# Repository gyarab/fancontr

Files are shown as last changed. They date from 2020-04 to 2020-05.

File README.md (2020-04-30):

# Rozcestník

- `dokumentace.pdf` -- Dokumentace v PDF
- `dokumentace/` -- Zdrojové soubory dokumentace
- `hw_foto/` -- Fotodokumentace hardwaru
- `firmware/` -- Zdrojový kód firmwaru
- `kicad_v1/` -- KiCad projekt hardwaru v1
	- `kicad_v1/fancontr.pdf` -- PDF schématu
	- `kicad_v1/bom/ibom.html` -- Interaktivní zobrazení tištěného spoje
- `kicad_v2_wip/` -- KiCad projekt hardwaru v2 (nefinální!)
	- `kicad_v2_wip/fancontr.pdf` -- PDF schématu
	- `kicad_v2_wip/bom/ibom.html` -- Interaktivní zobrazení tištěného spoje

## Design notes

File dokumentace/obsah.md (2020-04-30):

# Hardware

Hardwarová část ročníkové práce má formu zařízení, které je určeno k vložení do
počítače a připojení k jeho zdroji, je možné jej ale používat i mimo počítač s
externím zdrojem.

Návrh obvodu a tištěného spoje byl proveden v svobodném softwaru KiCad a
tištěné spoje vyrobila společnost JiaLiChuang Co., Limited (JLCPCB)[^101].

Jako součást ročníkové práce odevzdávám první verzi hardwaru, v1, která je zde
dále popsána.

Hardware řídí mikrokontrolér STM32F103C8T6[^102] založený na jádře ARM
Cortex-M3.  Přímo na něj je napojeno pět konektorů pro čtyřpinové ventilátory,
které jsou přímo regulovány PWM výstupem mikrokontroléru. Dalších šest
třípinových ventilátorů je regulováno obvodem na bázi spínacího zdroje.

Regulační obvod třípinových ventilátorů

Tento obvod lze rozdělit na část spínací a filtrační. Hlavní komponentou
spínací části je P-kanálový MOSFET, který je aktivován jednoduchou kombinací
N-kanálového MOSFETu a pull-up resistoru. Filtrační část pak sestává z LC
low-pass filtru. Využití high-side přepínání umožňuje připojit
tachometrický signál přímo k mikrokontroléru, jelikož zem ventilátoru je
připojena přímo k celkové zemi zařízení.

Součástí zařízení je i USB konektor, který měl sloužit ke komunikaci s
počítačem. I přes použití referenčního designu od výrobce mikrokontroléru ale
není rozhraní v aktuální verzi USB funkční, je tedy místo něj používán sériový
port s dedikovaným převodníkem.

[^101]: <https://jlcpcb.com/>
[^102]: <https://www.st.com/en/microcontrollers-microprocessors/stm32f103c8.html>

# Software

Firmware je napsán v jazyce C nad operačním systémem ChibiOS. Dokáže bez
připojení k externímu zařízení automaticky regulovat otáčky ventilátorů podle
teplotních dat.

Komunikace pro nastavování teplotně-otáčkových křivek a případné aktualizace
hodnot virtuálních zdrojů teplotních dat je realizována příkazovou řádkou. Tuto
komunikaci lze provádět manuálně s pomocí jakéhokoliv sériového terminálu nebo
automatizovat.

## Přehled příkazů

- `fan_list`  
  Přehled všech portů na ventilátory a rychlosti k nim aktuálně připojených
  ventilátorů.
- `fan_set_tempsrc <fan> <tempsrc>`  
  Nastaví zdroj teplotních dat, který bude řídit rychlost daného ventilátoru.
- `fan_set_gmap <fan> (<temp> <speed>)+`  
  Nastaví křivku závislosti rychlosti ventilátoru na teplotě.
- `fan_get_gmap <fan>`  
  Vypíše křivku závislosti rychlosti ventilátoru na teplotě.
- `tempsrc_list`  
  Přehled všech zdrojů teplotních dat a jejich hodnot.
- `tempsrc_virt_set <tempsrc> <value>`  
  Nastaví hodnotu zdroje teplotních dat.

# Diskuse

## Hardware

Hardwarová část projektu prošla v rámci vývoje několika iteracemi.

Nejproblematičtější částí byl obvod pro ovládání třípinových ventilátorů. Jeho
základní princip je skoro shodný s variabilním zdrojem napětí (buck DC-DC
converter), jen bez feedbacku. Kvůli nutnosti regulovat napětí digitálně z
mikrokontroléru by nebylo jednoduché použít levné čipy pro dedikované zdroje,
jelikož u těch se výstupní napětí definuje rezistivním děličem.  Dedikované
čipy s digitálním rozhraním jsou vesměs příliš drahé a zároveň i nepotřebně
výkonné.

První pokusy s low-side spínáním pomocí N-kanálového MOSFETu byly sice slibné,
ale nenašel jsem cestu, jak získat tachometrický signál. Napětí na kladném pinu
ventilátoru je v tomto obvodu totiž vždy 12V a mění se jeho záporný pin, který
není připojen přímo k zemi. Tachometrický signál ventilátoru je střídavě
plovoucí nebo připojený k zemi ventilátoru, která může mít vzhledem k
mikrokontroléru jakékoliv napětí mezi 0V a 12V.

Pro v1 tištěného spoje jsem zvolil low-side spínání P-kanálovým MOSFETem.
Ventilátor je tak připojen přímo k zemi celého obvodu a tachometrický signál
lze připojit přímo k mikrokontroléru. Tato varianta má ale výrazně horší
spínací vlastnosti: nezanedbatelná kapacitance gate pinu P-MOSFETu a odpor
pull-up rezistoru omezují minimální délku PWM pulzu na 12V straně obvodu, což
výrazně zvyšuje minimální otáčky připojeného ventilátoru. Tento problém lze
částečně vyřešit použitím pull-up rezistoru o menší hodnotě, což ale způsobí
výrazně větší tepelné ztráty na rezistoru.

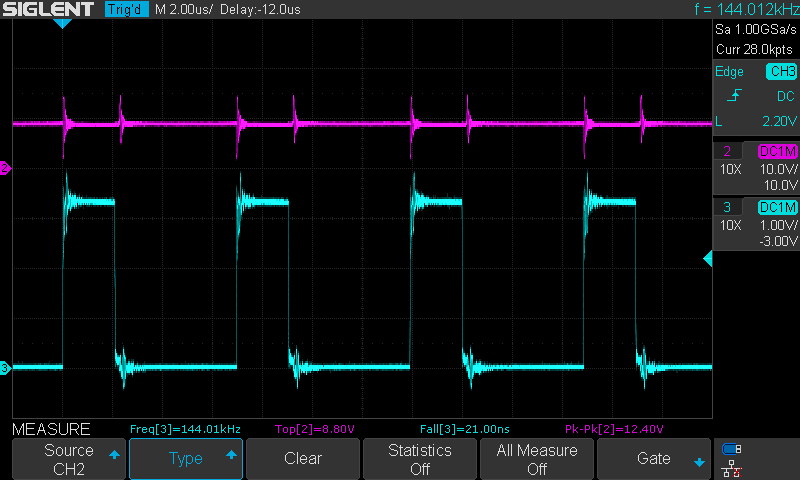
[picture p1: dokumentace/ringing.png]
"Gate ringing" (modře gate MOSFETu, červeně napětí na zdroji)


Pro připravovanou verzi v2 jsem zvolil opět low-side spínání a přidal jsem
komparátor na tachometrický signál, který je jím porovnáván vůči referenčnímu
11V napětí. Narazil jsem na fenomén nazývaný "gate ringing", vysokofrekvenční
oscilace na gate pinu MOSFETu způsobené rychlým přepínáním. Tyto oscilace by
mohly poškodit ventilátor nebo i počítač, ve kterém je zařízení umístěno.
Jejich vzniku jsem dostatečně zamezil přidáním rezistoru mezi gate a
mikrokontrolér.

Jednou z původně plánovaných vlastností projektu byla možnost funkce bez
připojení přes USB. V tomto případě by získával software informace o teplotě
chlazených komponent připojením do ventilátorového portu základní desky. V
první verzi hardwaru však kvůli limitaci ze strany mikrokontroléru nelze
zároveň měřit tento vstupní signál a otáčky ventilátoru číslo 9, jelikož oba
vstupní piny sdílí linku externího interruptu.

I přes značnou snahu se mi nepodařilo zprovoznit komunikaci přes USB. Původní
obvod neobsahoval žádné sériové rezistory na datových linkách, jelikož je
nezmiňují oficiální dokumenty od ST[^301]. V procesu hledání chyby jsem se
pokusil přímo použít obvod ze své vývojové desky, kde USB funguje. Jediný
rozdíl byla hodnota pull-up rezistoru pro D+ a 22Ω sériové rezistory na D+ a
D-, i po jejich přidání ale zařízení nenaváže úspěšně komunikaci přes USB.

[^301]: <https://www.st.com/resource/en/application_note/dm00296349-usb-hardware-and-pcb-guidelines-using-stm32-mcus-stmicroelectronics.pdf>

## Software

Software jsem se nejprve rozhodl napsat v programovacím jazyce Rust[^351],
který se svými vlastnostmi hodí pro programování mikrokontrolérů. Jeho zaměření
na compile-time záruky je žádoucí vzhledem k dlouhému procesu nahrávání
firmwaru do flash paměti. Bohužel knihovny pro interakci s hardwarem
mikrokontrolérů pro Rust[^352] jsou aktuálně ve fázi překotného vývoje a jejich
použití na složitější programy může jednoduše narazit na nevypilované části
designu.

Krom Rustu jsem zkoušel ještě několik jazyků a knihoven:

Platforma Arduino[^353] [^354] má sice velmi jednoduché rozhraní a není ani
náročná na paměť, ale její abstrakce překrývají některé detaily hardwaru, které
jsou pro jakékoliv složitější projekty důležité (například časování PWM výstupů
nebo limity externích interruptů STM32).

Platforma Mbed[^355] by se dala popsat jako evoluce Arduina. Využívá C++ a
poskytuje také velmi jednoduché rozhraní, dbá přitom více na zásady organizace
kódu a programátor si tak může vybrat úroveň abstrakce vhodnou pro jeho
projekt. Tato flexibilita ale zvětšuje výsledné soubory natolik, že program se
všemi funkcemi by se nemusel vejít do paměti mikrokontroléru. Zároveň jsem
narazil na různé problémy s build systémem, ať už při používání oficiálního
`mbed-cli` nebo populárního PlatformIO.

Platforma ChibiOS[^356] už není tak jednoduchá jako Arduino nebo Mbed, ale zato
poskytuje přístup ke všem potřebným detailům hardwaru a má i obsáhlé kontroly
konfigurace, které zjednodušují použití jinak na první pohled složitého
systému. Je i velmi nenáročná na paměť.

Projekt ChibiOS je rozdělen na několik částí, z nichž jsem použil ChibiOS/RT,
takzvaný "real-time operační systém", a ChibiOS/HAL, abstrakční vrstvu nad
přímou interakcí s hardwarem.

[^351]: <https://www.rust-lang.org/>
[^352]: <https://github.com/stm32-rs/stm32f1xx-hal>
[^353]: <https://www.arduino.cc/>
[^354]: <https://github.com/stm32duino/Arduino_Core_STM32>
[^355]: <https://os.mbed.com/>
[^356]: <http://chibios.org/dokuwiki/doku.php>

# Závěr

Tento projekt začal jako snaha vyřešit problémy s chlazením vlastního počítače.
V rámci práce se mi podařilo vytvořit funkční produkt, který plní svůj účel.
Jako každá první verze má i on své nedostatky. Ty však nejsou nepřekonatelné a
doufám, že s dalším úsilím a díky nově nabytým znalostem a zkušenostem dokáži i
je vyřešit a použít výsledný hardware ve svém počítači.

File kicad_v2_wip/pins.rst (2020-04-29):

PWM timers
==========

3pin
----

- PB0: TIM3_CH3
- PB4: TIM3_CH1
- PB5: TIM3_CH2
- PB6: TIM4_CH1
- PB8: TIM4_CH3
- PB9: TIM4_CH4

4pin
----

- PA0: TIM2_CH1
- PA1: TIM2_CH2
- PA2: TIM2_CH3
- PA3: TIM2_CH4
- PB13: TIM1_CH1N

Tacho pins
==========

- PB1
- PA4
- PA5
- PA6
- PB7
- PA8
- PA10
- PB12
- PC13
- PC14
- PC15

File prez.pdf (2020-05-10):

## Fancontr

Ovladač počítačových ventilátorů Ročníková práce z programování 2019/2020

David Koňařík
prezentace RP, květen 2020

Gymnázium, Praha 6, Arabská 14

Úvod

Fancontr reguluje rychlost počítačových ventilátorů podle teplotních dat a uživatelem definovaných křivek. Součástí projektu je hardware i software.

Hardware

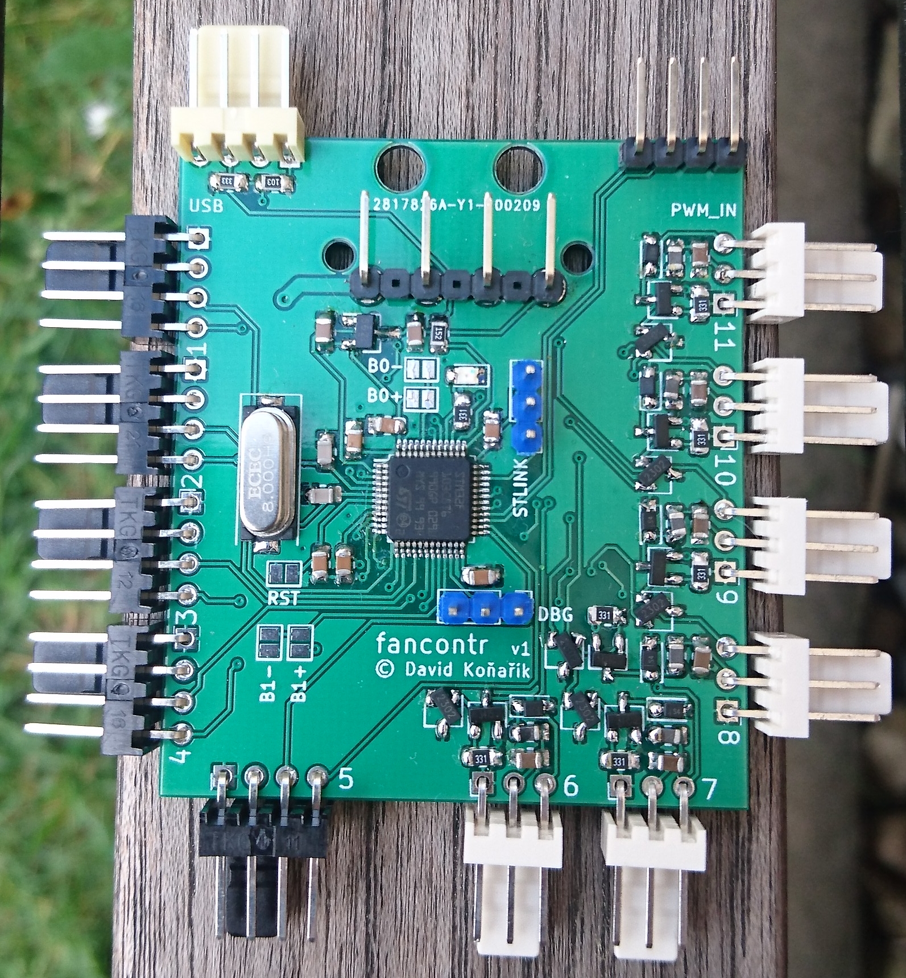
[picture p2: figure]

Součást RP je verze v1, v2 je ve vývoji.
- PCB vlastního návrhu
- Mikrokontrolér STM32F1
- Komunikace s PC přes
UART (původně USB)
- 5 × 4-pin a 6 × 3-pin
ventilátor

Hardware – 4-pin

Piny: GND, 12V, Tacho, PWM
Tacho signál je open-collector, indikuje rychlost otáčení. PWM signál je připojený na gate MOSFETu ve ventilátoru, na push-pull pin v MCU.
Tacho a PWM signály jsou oddělené, nedochází k rušení.

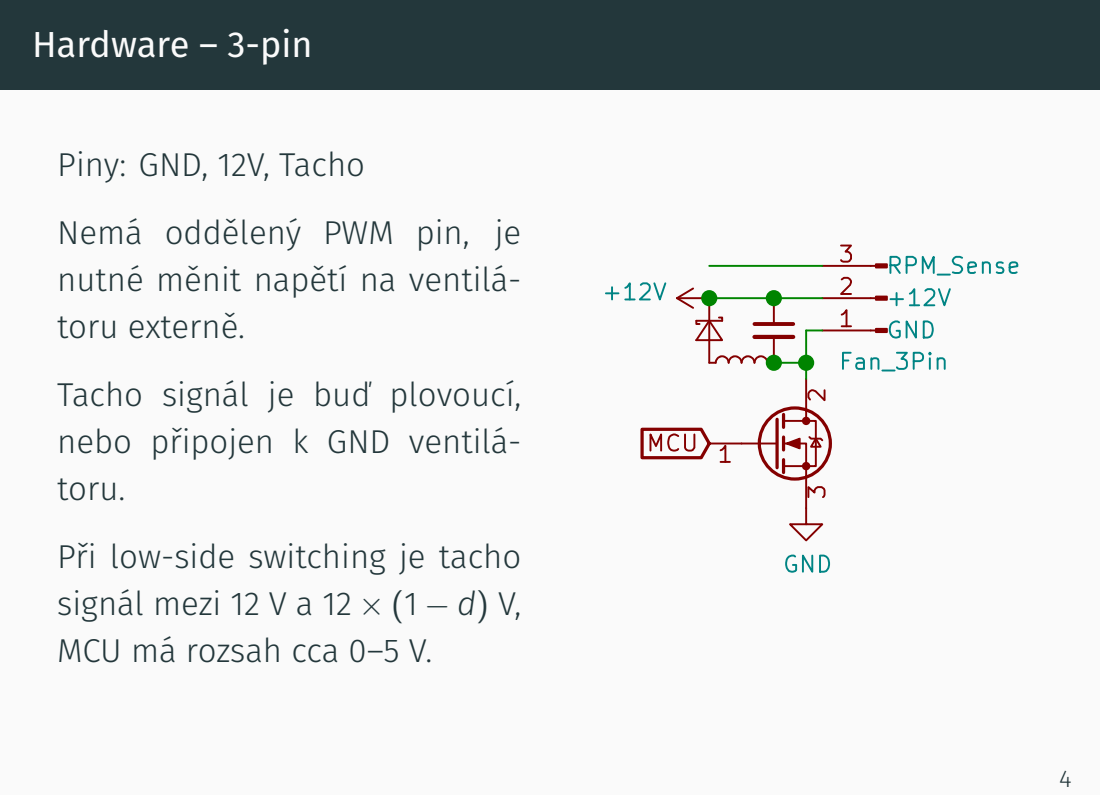
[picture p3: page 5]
Hardware – 3-pin; GND; RPM_Sense; Fan_3Pin; MCU

Piny: GND, 12V, Tacho
Nemá oddělený PWM pin, je
nutné měnit napětí na ventilá-
toru externě.
Tacho signál je buď plovoucí,
nebo připojen k GND ventilá-
toru.
Při low-side switching je tacho
signál mezi 12 V a 12
MCU má rozsah cca 0–5 V.

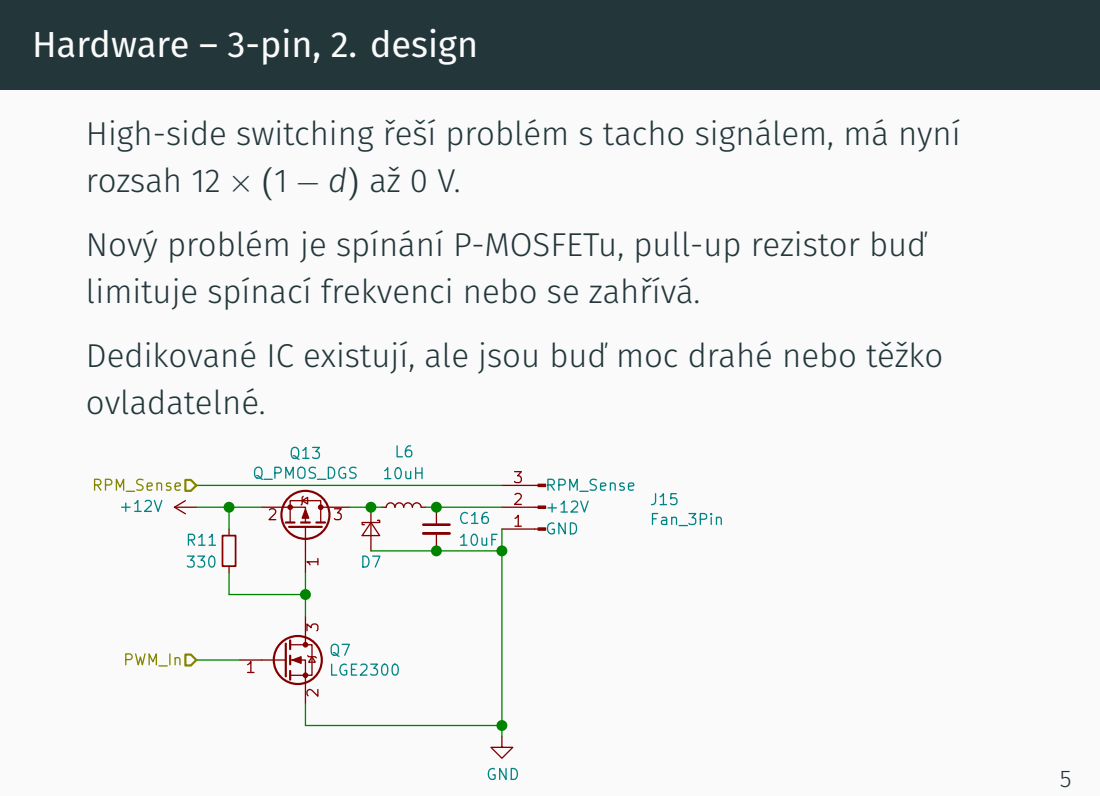
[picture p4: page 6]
GND; GND 1; RPM_Sense 3; J15 Fan_3Pin; Q13 Q_PMOS_DGS; Q7 LGE2300; PWM_In; RPM_Sense

Hardware – 3-pin, 2. design

High-side switching řeší problém s tacho signálem, má nyní
rozsah 12 × (1 − d) až 0 V.
Nový problém je spínání P-MOSFETu, pull-up rezistor buď
limituje spínací frekvenci nebo se zahřívá.
Dedikované IC existují, ale jsou buď moc drahé nebo těžko
ovladatelné.

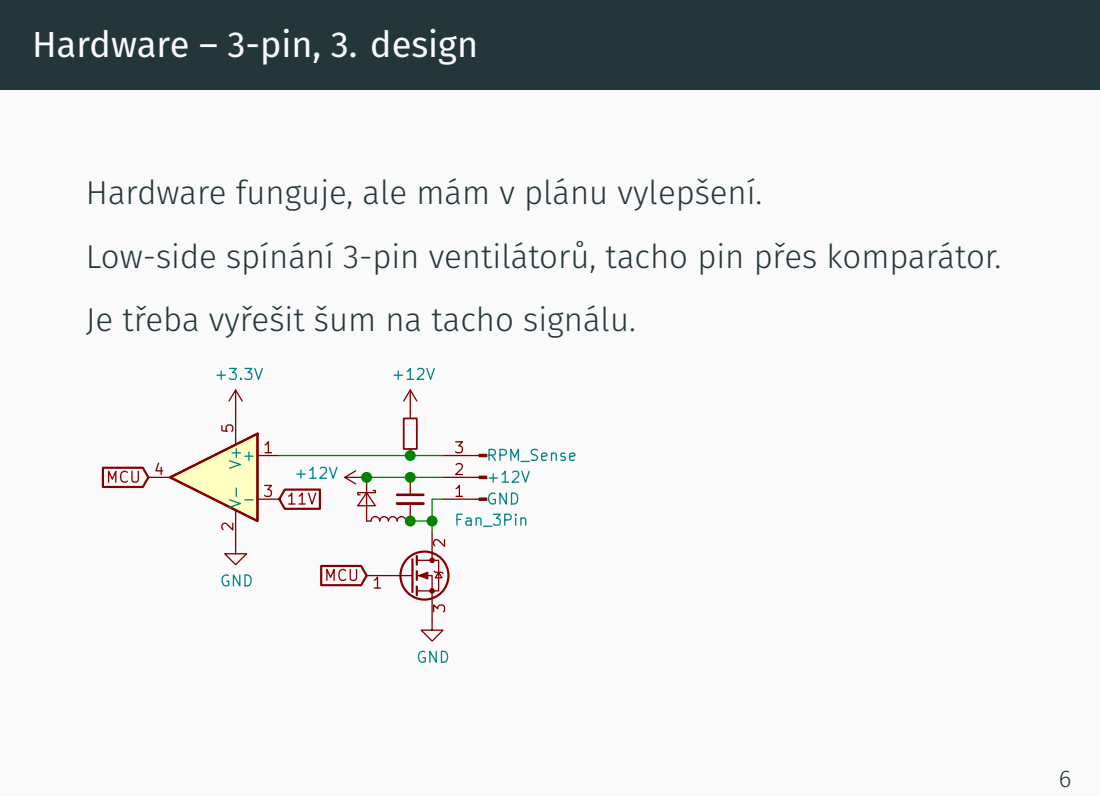
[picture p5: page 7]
GND; GND 1; RPM_Sense 3; Fan_3Pin; MCU

Hardware – 3-pin, 3. design

Hardware funguje, ale mám v plánu vylepšení.
Low-side spínání 3-pin ventilátorů, tacho pin přes komparátor.
Je třeba vyřešit šum na tacho signálu.

Hardware – prototyp v2

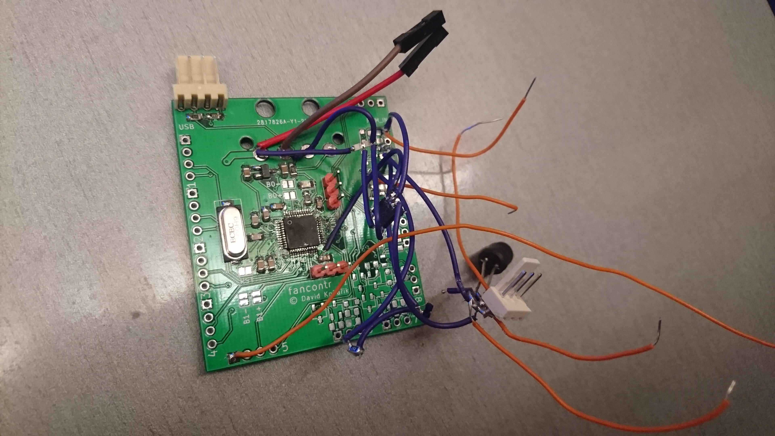
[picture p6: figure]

Software

Firmware je napsaný nad ChibiOS v jazyce C.
Využívá vlákna, časovače a interrupty.
Není potřeba real-time přesnost, stačí časovač 10 Hz a interrupt max 100 Hz.

Software – CLI

> fan_list
- name: 1
is 4 pin: yes
rpm: 1065
> tempsrc_list
- name: virt_1
temp: 43
> fan_set_gmap 1 40 10 50 30 60 70 70 100 > fan_set_tempsrc 1 virt_3
> tempsrc_virt_set virt_3 55

Závěr

Aktuálně projekt funguje, existují ale možná vylepšení

- Efektivnější spínání 3-pin ventilátorů
- Regulace na základě cílové teploty a křivky pro individuální ventilátory
- Grafické rozhraní pro uživatele
- Připojení přes USB

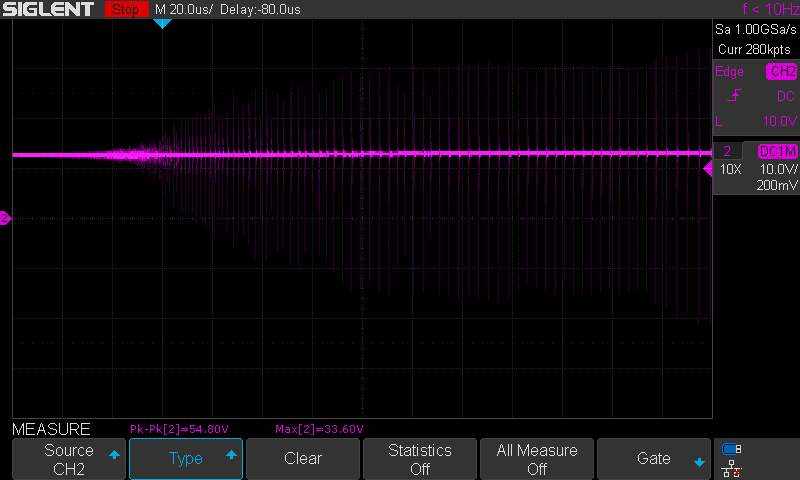
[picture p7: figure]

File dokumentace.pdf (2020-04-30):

# Ročníková a maturitní práce

# Ovladač počítačových ventilátorů

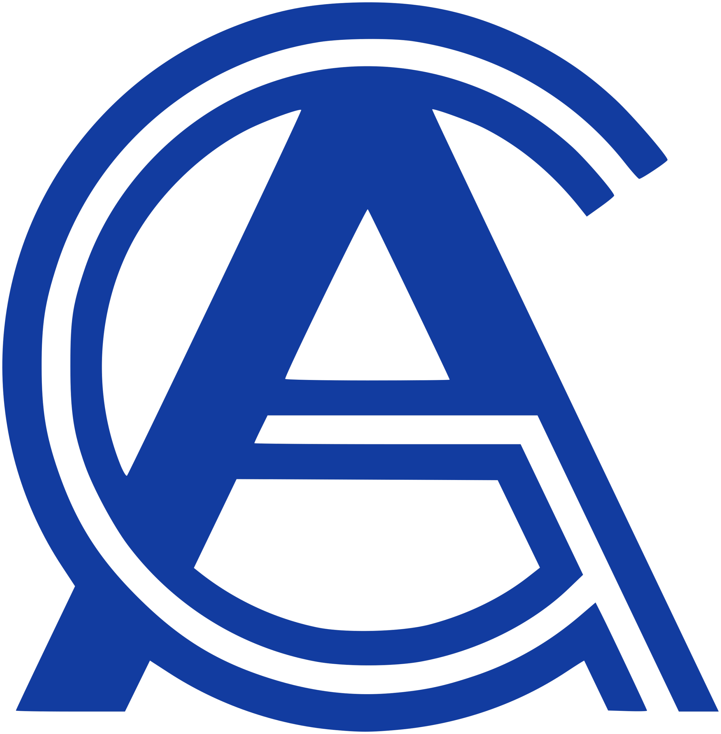
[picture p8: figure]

### Autor: David Koňařík Škola: Gymnázium, Praha 6, Arabská 14 Ročník: 4. E 2019/2020

# Anotace

Cílem mé práce bylo vytvořit hardware a software pro automatické ovládání počítačových ventilátorů. Výsledný hardware zvládá regulovat oba běžně používané typy ventilátorů, třípinové i čtyřpinové, a poskytuje uživateli mnoho možností pro nastavení.

Prohlašuji, že jsem jediným autorem tohoto projektu, všechny citace jsou řádně označené a všechna použitá literatura a další zdroje jsou v práci uvedené. Tímto dle zákona 121/2000 Sb. (tzv. Autorský zákon) ve znění pozdějších předpisů uděluji bezúplatně škole Gymnázium, Praha 6, Arabská14 oprávnění k výkonu práva na rozmnožování díla (§ 13) a práva na sdělování díla veřejnosti (§ 18) na dobu časově neomezenou a bez omezení územního rozsahu.

1

# Obsah

1 Hardware | 3
2 Software | 5
3 Diskuse | 6
4 Závěr | 9

2

# Kapitola 1

# Hardware

Hardwarová část ročníkové práce má formu zařízení, které je určeno k vložení do počítače a připojení k jeho zdroji, je možné jej ale používat i mimo počítač s externím zdrojem.
Návrh obvodu a tištěného spoje byl proveden v svobodném softwaru KiCad a tištěné spoje vyrobila společnost JiaLiChuang Co., Limited (JLCPCB)¹
Jako součást ročníkové práce odevzdávám první verzi hardwaru, v1, která je zde dále popsána.
Hardware řídí mikrokontrolér STM32F103C8T6²
založený na jádře ARM
Cortex-M3. Přímo na něj je napojeno pět konektorů pro čtyřpinové ventilátory, které jsou přímo regulovány PWM výstupem mikrokontroléru. Dalších šest třípinových ventilátorů je regulováno obvodem na bázi spínacího zdroje. Tento obvod lze rozdělit na část spínací a filtrační. Hlavní komponentou spínací části je P-kanálový MOSFET, který je aktivován jednoduchou kombinací N-kanálového MOSFETu a pull-up resistoru. Filtrační část pak sestává z LC low-pass filtru. Využití high-side přepínání umožňuje připojit tachometrický signál přímo k mikrokontroléru, jelikož zem ventilátoru je připojena přímo k

GND

GND 1

+12V 2

RPM_Sense 3
J15
Fan_3Pin

+12V

1

2 3
Q7
LGE2300

1

2 | 3

Q13
Q_PMOS_DGS

D7
D_Small

C16
10uF

L6
10uH

R11
750

PWM_In

RPM_Sense

Obrázek 1.1: Regulační obvod třípinových ventilátorů

1https://jlcpcb.com/
2https://www.st.com/en/microcontrollers-microprocessors/stm32f103c8.html

3

celkové zemi zařízení.
Součástí zařízení je i USB konektor, který měl sloužit ke komunikaci s počítačem. I přes použití referenčního designu od výrobce mikrokontroléru ale není rozhraní v aktuální verzi USB funkční, je tedy místo něj používán sériový port s dedikovaným převodníkem.

4

# Kapitola 2

# Software

Firmware je napsán v jazyce C nad operačním systémem ChibiOS. Dokáže bez připojení k externímu zařízení automaticky regulovat otáčky ventilátorů podle teplotních dat.
Komunikace pro nastavování teplotně-otáčkových křivek a případné aktualizace hodnot virtuálních zdrojů teplotních dat je realizována příkazovou řádkou. Tuto komunikaci lze provádět manuálně s pomocí jakéhokoliv sériového terminálu nebo automatizovat.

## 2.1 Přehled příkazů

- fan_list
Přehled všech portů na ventilátory a rychlosti k nim aktuálně připojených ventilátorů.
- fan_set_tempsrc <fan> <tempsrc>
Nastaví zdroj teplotních dat, který bude řídit rychlost daného ventilátoru.
- fan_set_gmap <fan> (<temp> <speed>)+
Nastaví křivku závislosti rychlosti ventilátoru na teplotě.
- fan_get_gmap <fan>
Vypíše křivku závislosti rychlosti ventilátoru na teplotě.
- tempsrc_list
Přehled všech zdrojů teplotních dat a jejich hodnot.
- tempsrc_virt_set <tempsrc> <value>
Nastaví hodnotu zdroje teplotních dat.

5

# Kapitola 3

# Diskuse

## 3.1 Hardware

Hardwarová část projektu prošla v rámci vývoje několika iteracemi. Nejproblematičtější částí byl obvod pro ovládání třípinových ventilátorů. Jeho základní princip je skoro shodný s variabilním zdrojem napětí (buck DC-DC converter), jen bez feedbacku. Kvůli nutnosti regulovat napětí digitálně z mikrokontroléru by nebylo jednoduché použít levné čipy pro dedikované zdroje, jelikož u těch se výstupní napětí definuje rezistivním děličem. Dedikované čipy s digitálním rozhraním jsou vesměs příliš drahé a zároveň i nepotřebně výkonné. První pokusy s low-side spínáním pomocí N-kanálového MOSFETu byly sice slibné, ale nenašel jsem cestu, jak získat tachometrický signál. Napětí na kladném pinu ventilátoru je v tomto obvodu totiž vždy 12V a mění se jeho záporný pin, který není připojen přímo k zemi. Tachometrický signál ventilátoru je střídavě plovoucí nebo připojený k zemi ventilátoru, která může mít vzhledem k mikrokontroléru jakékoliv napětí mezi 0V a 12V.
Pro v1 tištěného spoje jsem zvolil low-side spínání P-kanálovým MOSFE-Tem. Ventilátor je tak připojen přímo k zemi celého obvodu a tachometrický signál lze připojit přímo k mikrokontroléru. Tato varianta má ale výrazně horší spínací vlastnosti: nezanedbatelná kapacitance gate pinu P-MOSFETu a odpor pull-up rezistoru omezují minimální délku PWM pulzu na 12V straně obvodu, což výrazně zvyšuje minimální otáčky připojeného ventilátoru. Tento problém lze částečně vyřešit použitím pull-up rezistoru o menší hodnotě, což ale způsobí výrazně větší tepelné ztráty na rezistoru.
Pro připravovanou verzi v2 jsem zvolil opět low-side spínání a přidal jsem komparátor na tachometrický signál, který je jím porovnáván vůči referenčnímu 11V napětí. Narazil jsem na fenomén nazývaný “gate ringing”, vysokofrekvenční oscilace na gate pinu MOSFETu způsobené rychlým přepínáním. Tyto oscilace by mohly poškodit ventilátor nebo i počítač, ve kterém je zařízení umístěno. Jejich vzniku jsem dostatečně zamezil přidáním rezistoru mezi gate a mikrokontrolér.
Jednou z původně plánovaných vlastností projektu byla možnost funkce bez připojení přes USB. V tomto případě by získával software informace o teplotě chlazených komponent připojením do ventilátorového portu základní desky. V první verzi hardwaru však kvůli limitaci ze strany mikrokontroléru nelze zároveň

6

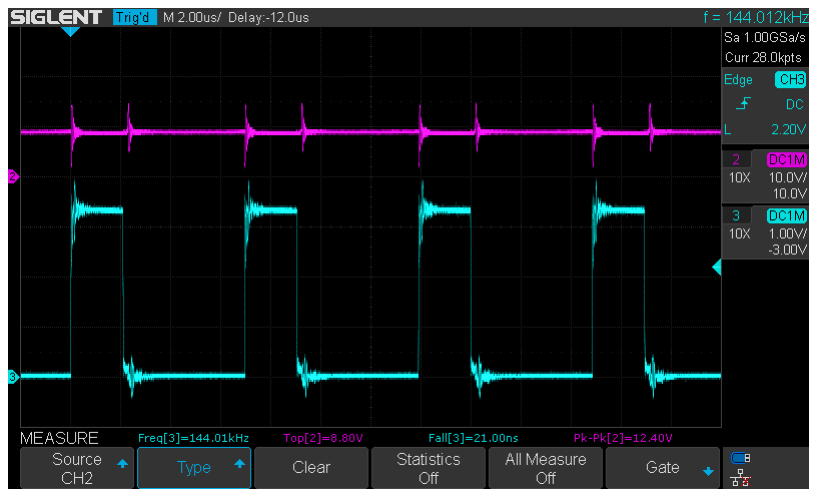
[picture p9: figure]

Obrázek 3.1: “Gate ringing” (modře gate MOSFETu, červeně napětí na zdroji)

měřit tento vstupní signál a otáčky ventilátoru číslo 9, jelikož oba vstupní piny sdílí linku externího interruptu.
I přes značnou snahu se mi nepodařilo zprovoznit komunikaci přes USB. Původní obvod neobsahoval žádné sériové rezistory na datových linkách, jelikož je nezmiňují oficiální dokumenty od ST¹
. V procesu hledání chyby jsem se pokusil přímo použít obvod ze své vývojové desky, kde USB funguje. Jediný rozdíl byla hodnota pull-up rezistoru pro D+ a 22Ω sériové rezistory na D+ a D-, i po jejich přidání ale zařízení nenaváže úspěšně komunikaci přes USB.

## 3.2 Software

Software jsem se nejprve rozhodl napsat v programovacím jazyce Rust²
, který se svými vlastnostmi hodí pro programování mikrokontrolérů. Jeho zaměření na compile-time záruky je žádoucí vzhledem k dlouhému procesu nahrávání firmwaru do flash paměti. Bohužel knihovny pro interakci s hardwarem mikrokontrolérů pro Rust³
jsou aktuálně ve fázi překotného vývoje a jejich použití na složitější programy může jednoduše narazit na nevypilované části designu. Krom Rustu jsem zkoušel ještě několik jazyků a knihoven:
Platforma Arduino⁴ ⁵ má sice velmi jednoduché rozhraní a není ani náročná na paměť, ale její abstrakce překrývají některé detaily hardwaru, které jsou pro jakékoliv složitější projekty důležité (například časování PWM výstupů nebo limity externích interruptů STM32).
Platforma Mbed⁶ by se dala popsat jako evoluce Arduina. Využívá C++ a poskytuje také velmi jednoduché rozhraní, dbá přitom více na zásady organizace kódu a programátor si tak může vybrat úroveň abstrakce vhodnou pro jeho

1https://www.st.com/resource/en/application_note/dm00296349-usb-hardware-andpcb-guidelines-using-stm32-mcus-stmicroelectronics.pdf (https://www.st.com/resource/en/application_note/dm00296349-usb-hardware-and-pcb-guidelines-using-stm32-mcus-stmicroelectronics.pdf) 2https://www.rust-lang.org/
3https://github.com/stm32-rs/stm32f1xx-hal
4https://www.arduino.cc/
5https://github.com/stm32duino/Arduino_Core_STM326https://os.mbed.com/

7

projekt. Tato flexibilita ale zvětšuje výsledné soubory natolik, že program se všemi funkcemi by se nemusel vejít do paměti mikrokontroléru. Zároveň jsem narazil na různé problémy s build systémem, ať už při používání oficiálního mbed-cli nebo populárního PlatformIO.
Platforma ChibiOS⁷ už není tak jednoduchá jako Arduino nebo Mbed, ale zato poskytuje přístup ke všem potřebným detailům hardwaru a má i obsáhlé kontroly konfigurace, které zjednodušují použití jinak na první pohled složitého systému. Je i velmi nenáročná na paměť.
Projekt ChibiOS je rozdělen na několik částí, z nichž jsem použil Chibi-OS/RT, takzvaný “real-time operační systém”, a ChibiOS/HAL, abstrakční vrstvu nad přímou interakcí s hardwarem.

7http://chibios.org/dokuwiki/doku.php

8

# Kapitola 4

# Závěr

Tento projekt začal jako snaha vyřešit problémy s chlazením vlastního počítače. V rámci práce se mi podařilo vytvořit funkční produkt, který plní svůj účel. Jako každá první verze má i on své nedostatky. Ty však nejsou nepřekonatelné a doufám, že s dalším úsilím a díky nově nabytým znalostem a zkušenostem dokáži i je vyřešit a použít výsledný hardware ve svém počítači.

9

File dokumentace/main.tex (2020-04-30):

\documentclass[a4paper]{report}
\usepackage{fontspec}
\usepackage{polyglossia}
\usepackage{charter}
\usepackage{environ}
\PassOptionsToPackage{hyphens}{url}
\usepackage{hyperref}
\usepackage{graphicx}
\usepackage{titlesec}
\usepackage[bottom]{footmisc}
\usepackage{tikz}
\usetikzlibrary{calc, matrix}

\setdefaultlanguage{czech}
\PolyglossiaSetup{czech}{indentfirst=true}

\usepackage{lmodern}

% For Pandoc
\providecommand{\tightlist}{%
  \setlength{\itemsep}{0pt}\setlength{\parskip}{0pt}}

\setkeys{Gin}{keepaspectratio}

%\titleformat{\chapter}[display]
%	{\normalfont\bfseries}{}{0pt}{\Huge\thechapter\hspace{1cm}}

\begin{document}

\begin{titlepage}
	\vspace{9cm}
	{\centering\Huge Ročníková a maturitní práce \par}
	{\centering\huge Ovladač počítačových ventilátorů \par}

	\vspace{2cm}
	
	\begin{center}
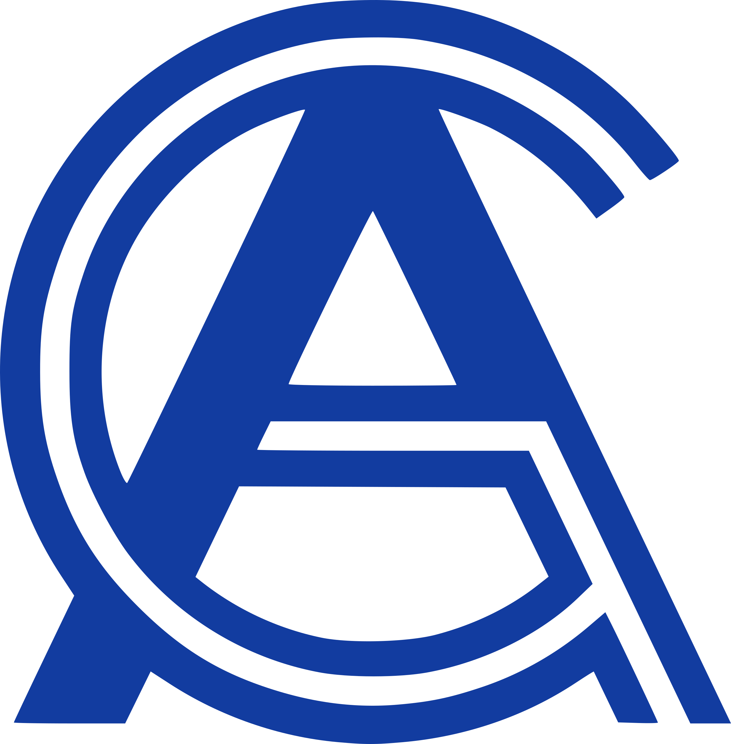
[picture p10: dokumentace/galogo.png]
	
	\end{center}

	\vfill

	{\large \textbf{Autor:} David Koňařík \par}
	{\large \textbf{Škola:} Gymnázium, Praha 6, Arabská 14 \par}
	{\large \textbf{Ročník:} 4. E 2019/2020 \par}
\end{titlepage}

\chapter*{Anotace}

Cílem mé práce bylo vytvořit hardware a software pro automatické ovládání
počítačových ventilátorů. Výsledný hardware zvládá regulovat oba běžně
používané typy ventilátorů, třípinové i čtyřpinové, a poskytuje uživateli mnoho
možností pro nastavení.

\vfill

Prohlašuji, že jsem jediným autorem tohoto projektu, všechny citace jsou řádně
označené a všechna použitá literatura a další zdroje jsou v práci uvedené.
Tímto dle zákona 121/2000 Sb. (tzv. Autorský zákon) ve znění pozdějších
předpisů uděluji bezúplatně škole Gymnázium, Praha 6, Arabská14 oprávnění k
výkonu práva na rozmnožování díla (§ 13) a práva na sdělování díla veřejnosti
(§ 18) na dobu časově neomezenou a bez omezení územního rozsahu.

\newpage

\tableofcontents
\newpage

\input{obsah.tex}

\end{document}

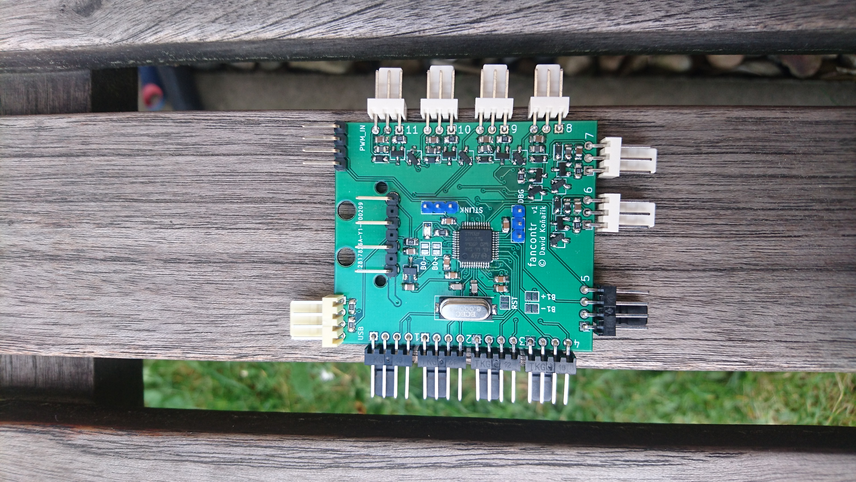
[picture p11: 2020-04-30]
hw_foto/front.jpg

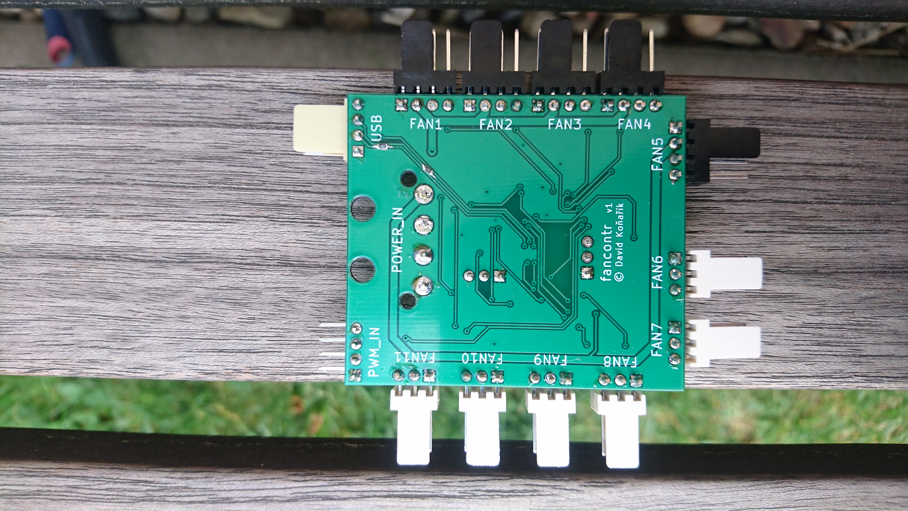
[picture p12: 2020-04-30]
hw_foto/back.jpg

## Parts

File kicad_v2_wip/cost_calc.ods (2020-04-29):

Description | Part number | Quantity | Unit cost | MOQ | Order cost (1 board) | Order cost (10 boards) | Link
Board components
100nF cap |  | 6 | 0.13 | 50 | 6.5 | 13
1uF cap |  | 2 | 0.16 | 50 | 8 | 8
10uF cap |  | 6 | 0.42 | 20 | 8.4 | 25.2
20pF cap |  | 2 | 0.12 | 50 | 6 | 6
10k resistor |  | 13 | 0.026 | 100 | 2.6 | 5.2
33k resistor |  | 12 | 0.026 | 100 | 2.6 | 5.2
1k resistor |  | 6 | 0.023 | 100 | 2.3 | 2.3
100 resistor |  | 1 | 0.023 | 100 | 2.3 | 2.3
1.5k resistor |  | 1 | 0.023 | 100 | 2.3 | 2.3
12V diode |  | 6 | 0.23 | 50 | 11.5 | 23
Main MCU | STM32F103C8Tx | 1 | 41.6 | 1 | 41.6 | 416
8MHz crystal |  | 1 | 1.45 | 5 | 7.25 | 14.5
MOSFET | BSS138 | 7 | 0.34 | 20 | 6.8 | 27.2
Molex power connector |  | 1 | 13.2 | 10 | 132 | 132 | https://www.aliexpress.com/item/32881783250.html
3-pin fan right angle |  |  |  |  | 0 | 0
4-pin fan right angle |  | 5 | 1.4 | 50 | 70 | 70 | https://www.aliexpress.com/item/32961935772.html
USB connector |  |  |  |  | 0 | 0
4-pin PWM IN connector |  |  |  |  | 0 | 0
Cables
4-pin PWM IN housing |  | 2 | 0.9 | 50 | 45 | 45 | https://www.aliexpress.com/item/32961935772.html
Pre-crimped wires |  | 8 | 0.7 | 20 | 14 | 56 | https://www.aliexpress.com/item/33009884363.html
 |  |  |  |  | Total cost (1 unit) | Unit cost (10 units)
 |  |  |  |  | 369.15 | 85.32

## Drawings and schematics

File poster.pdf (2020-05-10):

# Fancontr

## 5 portů pro 4-pin ventilátor

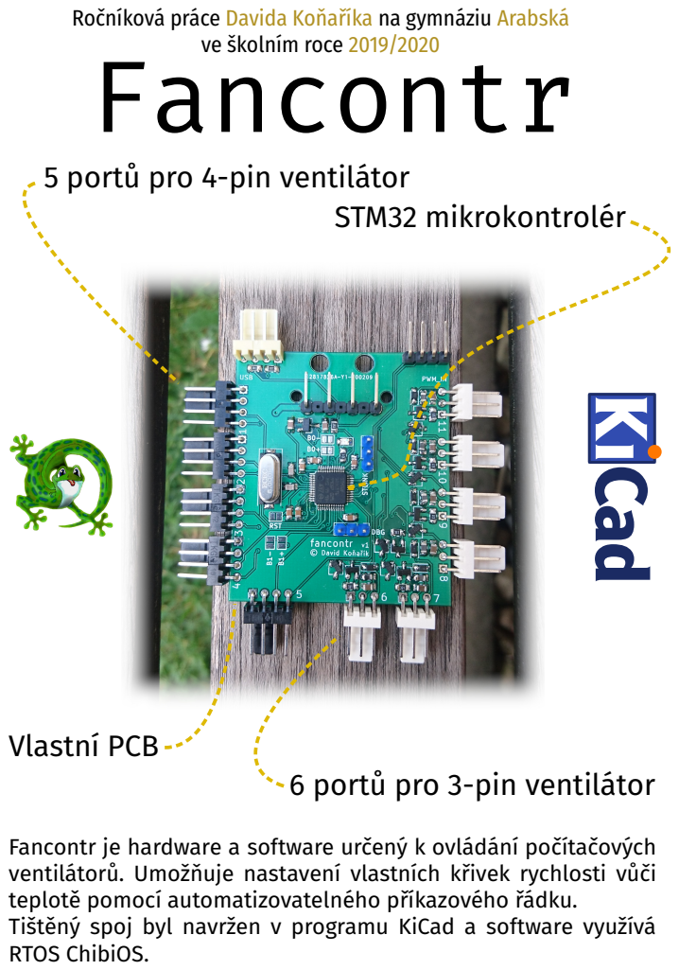
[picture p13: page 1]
STM32 mikrokontrolér; Vlastní PCB

Ročníková práce Davida Koňaříka na gymnáziu Arabská

ve školním roce 2019/2020

6 portů pro 3-pin ventilátor

Fancontr je hardware a software určený k ovládání počítačových
ventilátorů. Umožňuje nastavení vlastních křivek rychlosti vůči
teplotě pomocí automatizovatelného příkazového řádku.
Tištěný spoj byl navržen v programu KiCad a software využívá
RTOS ChibiOS.

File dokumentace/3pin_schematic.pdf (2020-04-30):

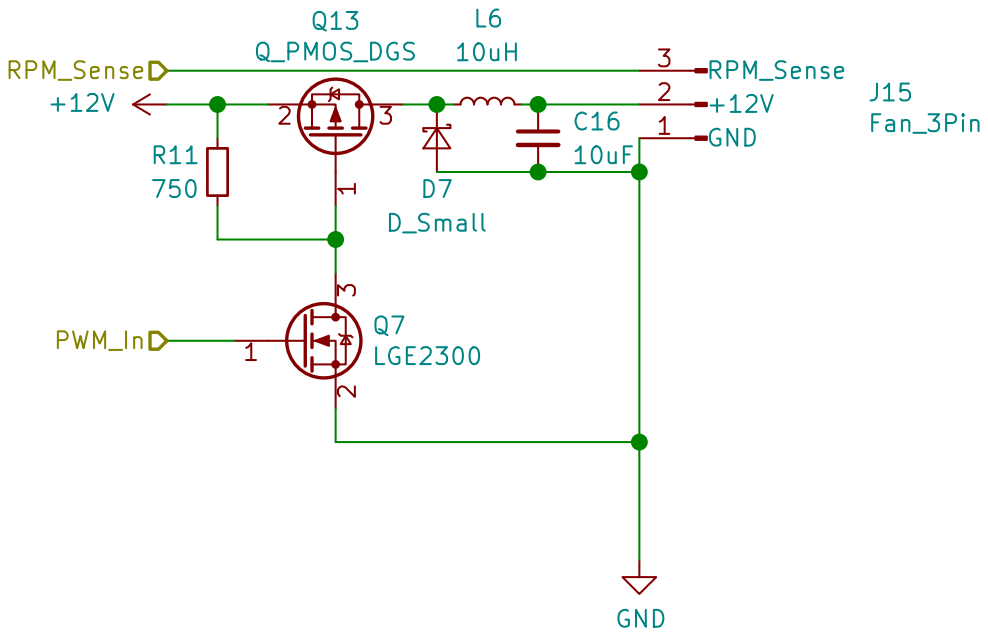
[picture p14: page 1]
GND; GND 1; RPM_Sense 3; J15 Fan_3Pin; Q7 LGE2300; Q13 Q_PMOS_DGS; D7 D_Small; PWM_In; RPM_Sense

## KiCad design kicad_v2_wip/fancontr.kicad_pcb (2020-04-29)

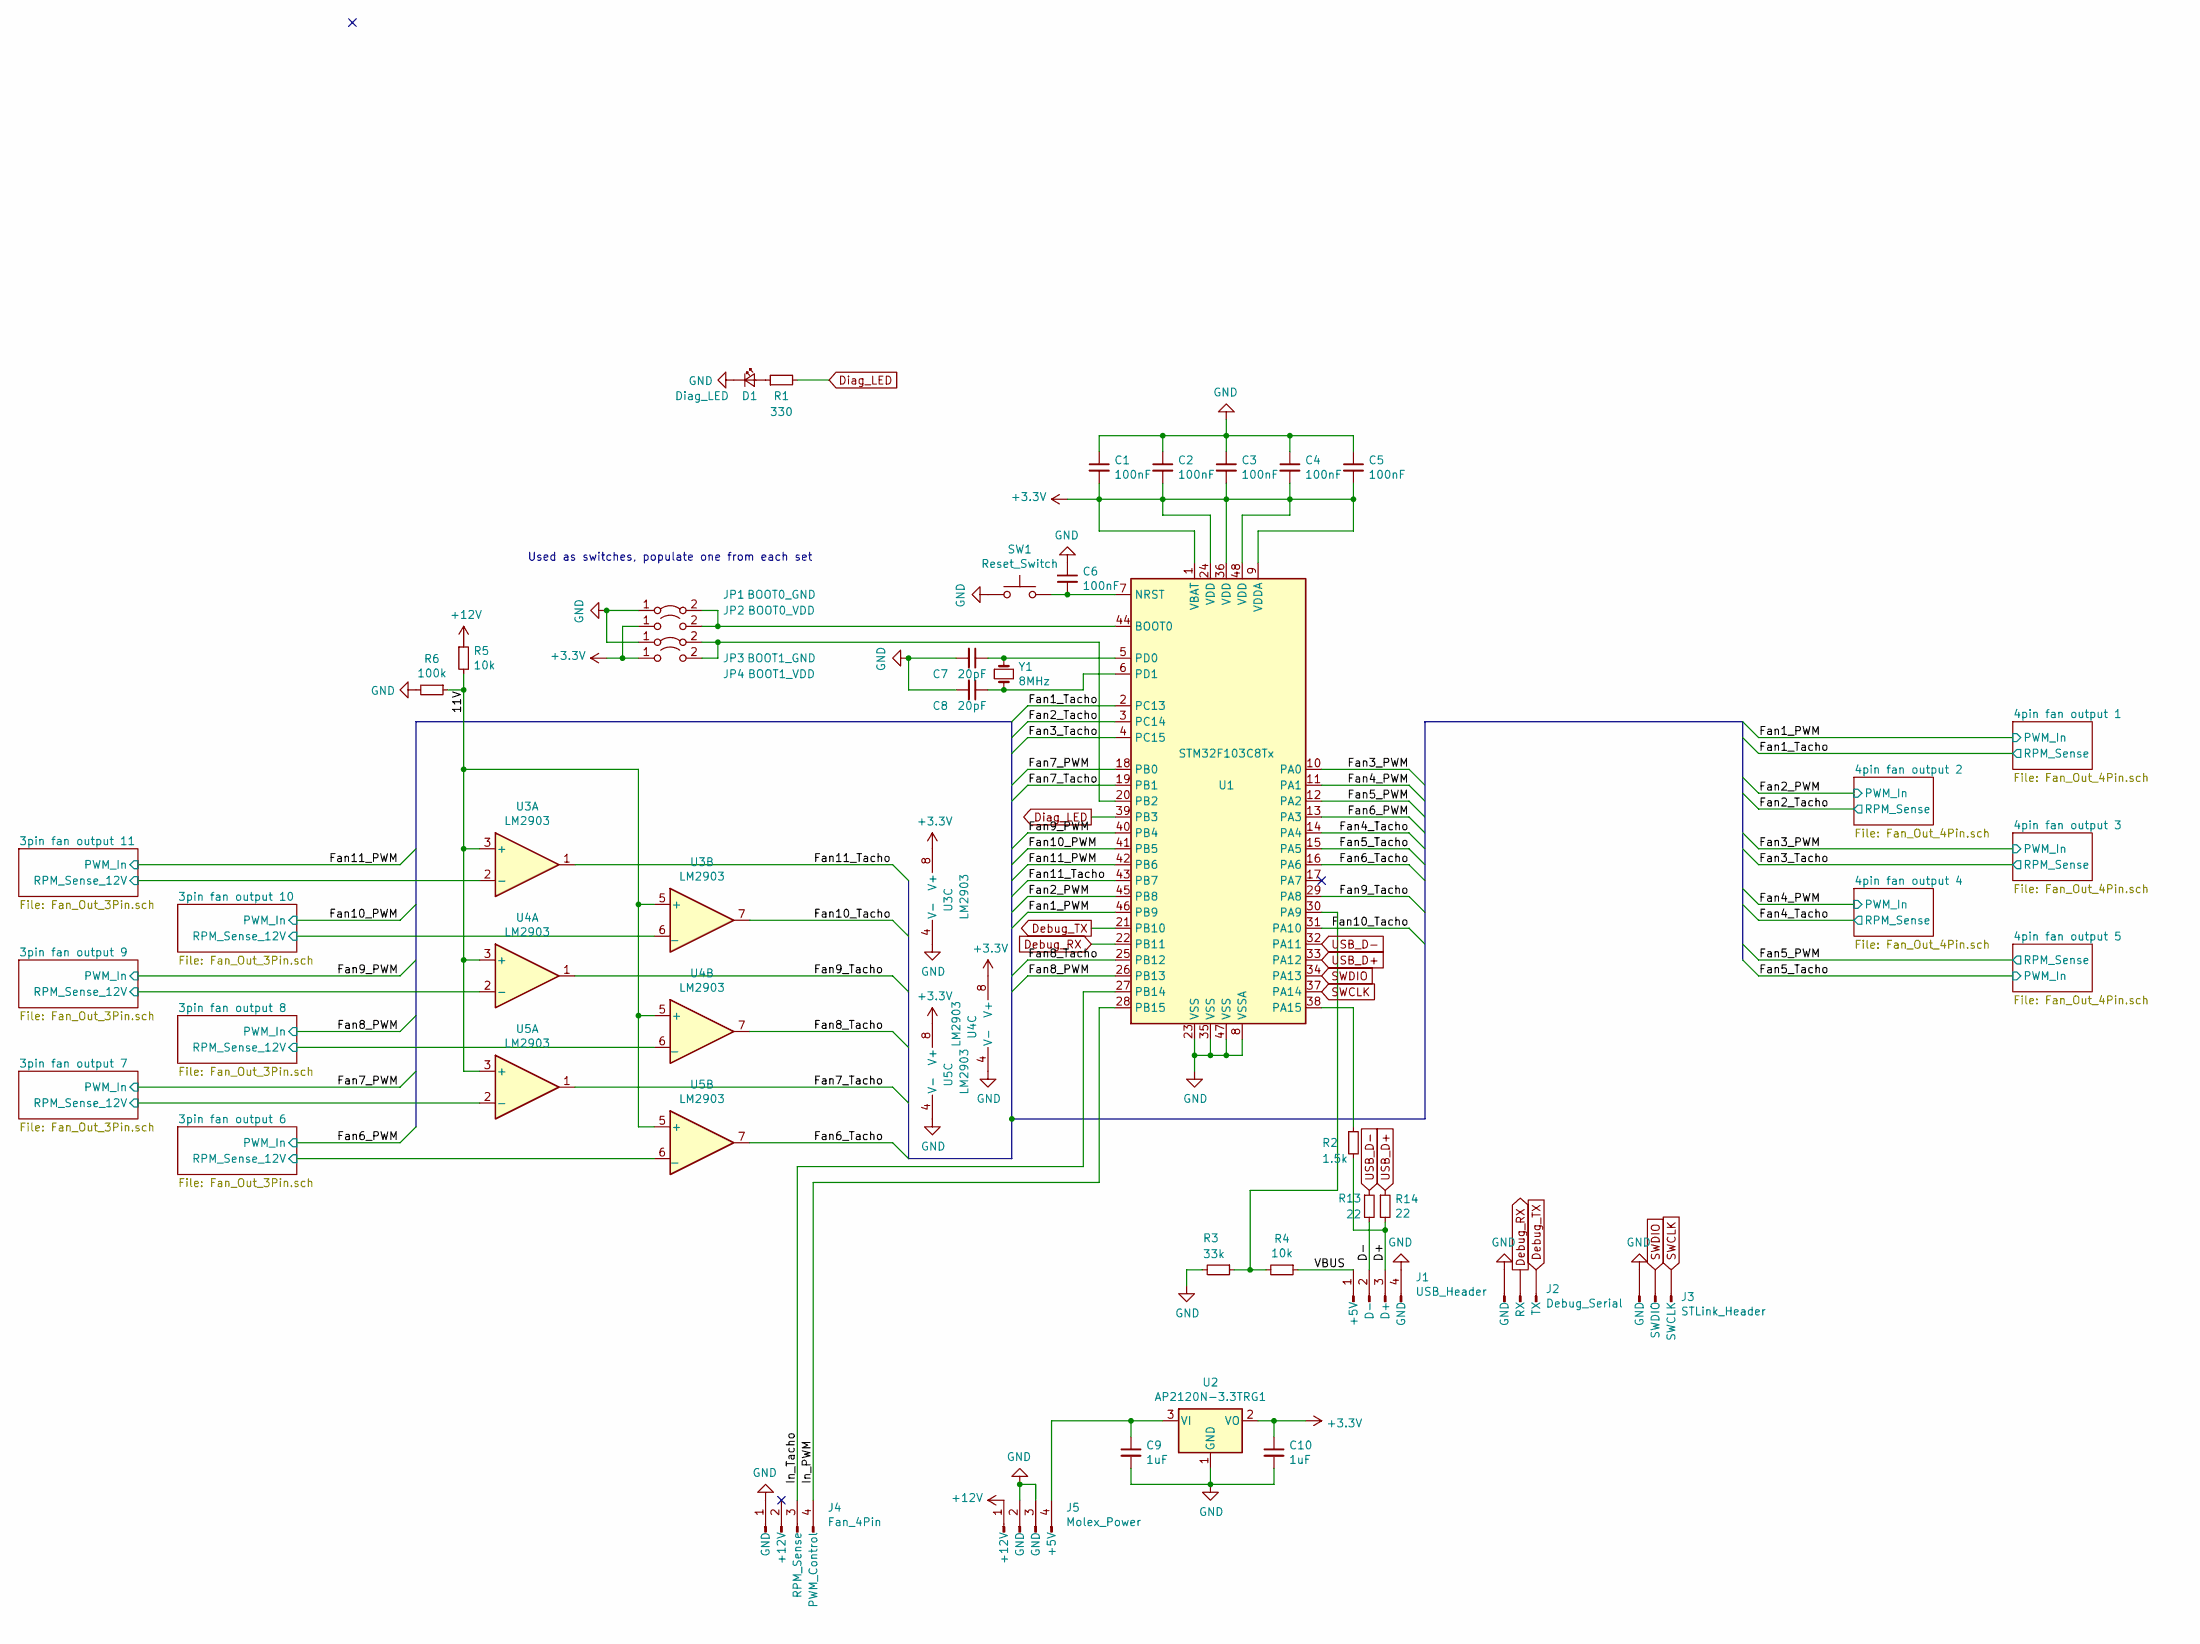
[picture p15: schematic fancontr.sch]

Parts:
C1, C2, C3, C4, C5, C6: 100nF; C_0805_2012Metric_Pad1.15x1.40mm_HandSolder
C7, C8: 20pF; C_0805_2012Metric_Pad1.15x1.40mm_HandSolder
C9, C10: 1uF; C_0805_2012Metric_Pad1.15x1.40mm_HandSolder
D1: Diag_LED; LED_0805_2012Metric_Castellated
J1: USB_Header; PinHeader_1x04_P2.54mm_Horizontal_NoSilk
J2: Debug_Serial; PinHeader_1x03_P2.54mm_Vertical
J3: STLink_Header; PinHeader_1x03_P2.54mm_Vertical
J4: Fan_4Pin; PinHeader_1x04_P2.54mm_Horizontal_NoSilk
J5: Molex_Power; MATE-N-LOK 641737-1
JP1: BOOT0_GND; SolderJumper-2_P1.3mm_Open_Pad1.0x1.5mm
JP2: BOOT0_VDD; SolderJumper-2_P1.3mm_Open_Pad1.0x1.5mm
JP3: BOOT1_GND; SolderJumper-2_P1.3mm_Open_Pad1.0x1.5mm
JP4: BOOT1_VDD; SolderJumper-2_P1.3mm_Open_Pad1.0x1.5mm
R1: 330; R_0805_2012Metric_Pad1.15x1.40mm_HandSolder
R2: 1.5k; R_0805_2012Metric_Pad1.15x1.40mm_HandSolder
R3: 33k; R_0805_2012Metric_Pad1.15x1.40mm_HandSolder
R4, R5: 10k; R_0805_2012Metric_Pad1.15x1.40mm_HandSolder
R6: 100k; R_0805_2012Metric_Pad1.15x1.40mm_HandSolder
R13, R14: 22; R_0805_2012Metric_Pad1.15x1.40mm_HandSolder
SW1: Reset_Switch; SolderJumper-2_P1.3mm_Open_Pad1.0x1.5mm
U1: STM32F103C8Tx; LQFP-48_7x7mm_P0.5mm
U2: AP2120N-3.3TRG1; SOT-23_Handsoldering
U3, U4, U5: LM2903; SOIC-8_3.9x4.9mm_P1.27mm
Y1: 8MHz; Crystal_SMD_HC49-SD

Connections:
+3V3: C1.2, C2.2, C3.2, C4.2, C5.2, C10.1, JP2.1 (A), JP4.1 (A), U1.1 (VBAT), U1.9 (VDDA), U1.24 (VDD), U1.36 (VDD), U1.48 (VDD), U2.2 (VO), U3.8 (V+), U4.8 (V+), U5.8 (V+)
+12V: J5.1 (+12V), R5.1; also elsewhere on the board
/3pin fan output 6/RPM_Sense_12V: U5.6 (_); also elsewhere on the board
/3pin fan output 7/RPM_Sense_12V: U5.2 (-); also elsewhere on the board
/3pin fan output 8/RPM_Sense_12V: U4.6 (_); also elsewhere on the board
/3pin fan output 9/RPM_Sense_12V: U4.2 (-); also elsewhere on the board
/3pin fan output 10/RPM_Sense_12V: U3.6 (_); also elsewhere on the board
/3pin fan output 11/RPM_Sense_12V: U3.2 (-); also elsewhere on the board
/11V: R5.2, R6.1, U3.3 (+), U3.5 (+), U4.3 (+), U4.5 (+), U5.3 (+), U5.5 (+)
/D+: J1.3 (D+), R2.2, R14.2
/D-: J1.2 (D-), R13.2
/Fan1_PWM: U1.46 (PB9); also elsewhere on the board
/Fan1_Tacho: U1.2 (PC13); also elsewhere on the board
/Fan2_PWM: U1.45 (PB8); also elsewhere on the board
/Fan2_Tacho: U1.3 (PC14); also elsewhere on the board
/Fan3_PWM: U1.10 (PA0); also elsewhere on the board
/Fan3_Tacho: U1.4 (PC15); also elsewhere on the board
/Fan4_PWM: U1.11 (PA1); also elsewhere on the board
/Fan4_Tacho: U1.14 (PA4); also elsewhere on the board
/Fan5_PWM: U1.12 (PA2); also elsewhere on the board
/Fan5_Tacho: U1.15 (PA5); also elsewhere on the board
/Fan6_PWM: U1.13 (PA3); also elsewhere on the board
/Fan6_Tacho: U1.16 (PA6), U5.7
/Fan7_PWM: U1.18 (PB0); also elsewhere on the board
/Fan7_Tacho: U1.19 (PB1), U5.1
/Fan8_PWM: U1.26 (PB13); also elsewhere on the board
/Fan8_Tacho: U1.25 (PB12), U4.7
/Fan9_PWM: U1.40 (PB4); also elsewhere on the board
/Fan9_Tacho: U1.29 (PA8), U4.1
/Fan10_PWM: U1.41 (PB5); also elsewhere on the board
/Fan10_Tacho: U1.31 (PA10), U3.7
/Fan11_PWM: U1.42 (PB6); also elsewhere on the board
/Fan11_Tacho: U1.43 (PB7), U3.1
/In_PWM: J4.4 (PWM_Control), U1.28 (PB15)
/In_Tacho: J4.3 (RPM_Sense), U1.27 (PB14)
/VBUS: J1.1 (+5V), R4.1
Debug_RX: J2.2 (RX), U1.22 (PB11)
Debug_TX: J2.3 (TX), U1.21 (PB10)
Diag_LED: R1.2, U1.39 (PB3)
GND: C1.1, C2.1, C3.1, C4.1, C5.1, C6.1, C7.2, C8.2, C9.2, C10.2, D1.1 (K), J1.4 (GND), J2.1 (GND), J3.1 (GND), J4.1 (GND), J5.2 (GND), J5.3 (GND), JP1.1 (A), JP3.1 (A), R3.2, R6.2, SW1.1, U1.8 (VSSA), U1.23 (VSS), U1.35 (VSS), U1.47 (VSS), U2.1 (GND), U3.4 (V-), U4.4 (V-), U5.4 (V-); also elsewhere on the board
unnamed: C6.2, SW1.2, U1.7 (NRST)
unnamed: C7.1, U1.5 (PD0), Y1.1
unnamed: C8.1, U1.6 (PD1), Y1.2
unnamed: C9.1, J5.4 (+5V), U2.3 (VI)
unnamed: D1.2 (A), R1.1
unnamed: JP1.2 (B), JP2.2 (B), U1.44 (BOOT0)
unnamed: JP3.2 (B), JP4.2 (B), U1.20 (PB2)
unnamed: R2.1, U1.38 (PA15)
unnamed: R3.1, R4.2, U1.30 (PA9)
SWCLK: J3.3 (SWCLK), U1.37 (PA14)
SWDIO: J3.2 (SWDIO), U1.34 (PA13)
USB_D+: R14.1, U1.33 (PA12)
USB_D-: R13.1, U1.32 (PA11)

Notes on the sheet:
Used as switches, populate one from each set

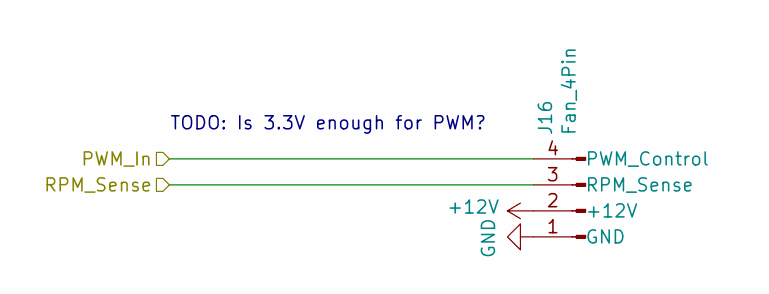
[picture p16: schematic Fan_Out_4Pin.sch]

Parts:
J6: Fan_4Pin; PinHeader_1x04_P2.54mm_Horizontal_NoSilk

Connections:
+12V: J6.2 (+12V); also elsewhere on the board
/Fan1_PWM: J6.4 (PWM_Control); also elsewhere on the board
/Fan1_Tacho: J6.3 (RPM_Sense); also elsewhere on the board
GND: J6.1 (GND); also elsewhere on the board

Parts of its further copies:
J7, J8, J9, J16: Fan_4Pin; PinHeader_1x04_P2.54mm_Horizontal_NoSilk

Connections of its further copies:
+12V: J7.2 (+12V), J8.2 (+12V), J9.2 (+12V), J16.2 (+12V); also elsewhere on the board
/Fan2_PWM: J7.4 (PWM_Control); also elsewhere on the board
/Fan2_Tacho: J7.3 (RPM_Sense); also elsewhere on the board
/Fan3_PWM: J8.4 (PWM_Control); also elsewhere on the board
/Fan3_Tacho: J8.3 (RPM_Sense); also elsewhere on the board
/Fan4_PWM: J9.4 (PWM_Control); also elsewhere on the board
/Fan4_Tacho: J9.3 (RPM_Sense); also elsewhere on the board
/Fan5_PWM: J16.3 (RPM_Sense); also elsewhere on the board
/Fan5_Tacho: J16.4 (PWM_Control); also elsewhere on the board
GND: J7.1 (GND), J8.1 (GND), J9.1 (GND), J16.1 (GND); also elsewhere on the board

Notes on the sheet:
TODO: Is 3.3V enough for PWM?

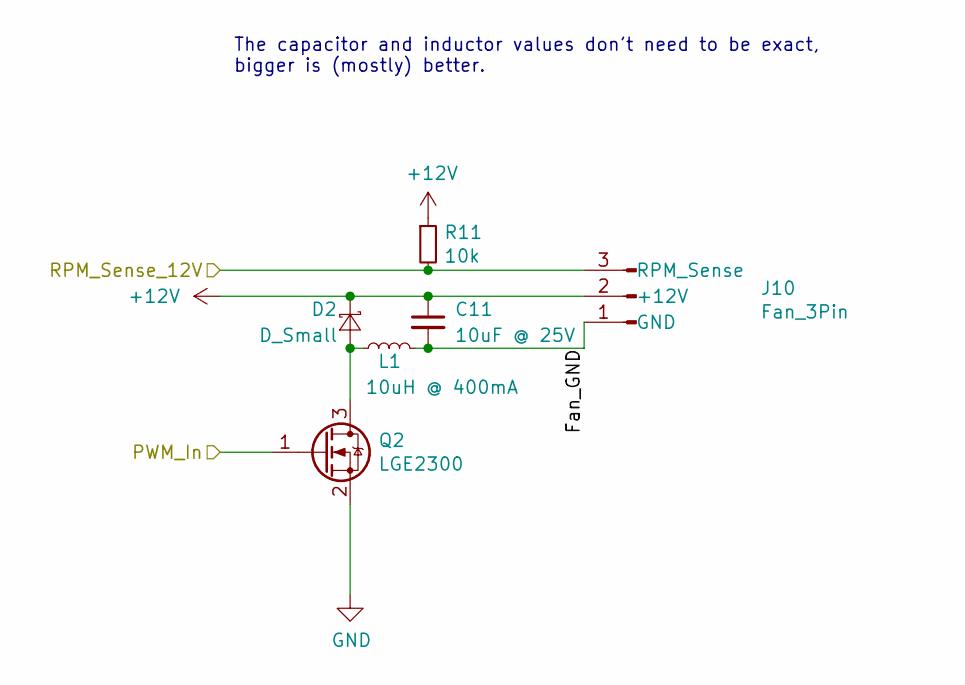
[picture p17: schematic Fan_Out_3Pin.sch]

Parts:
C16: 10uF @ 25V; C_0805_2012Metric_Pad1.15x1.40mm_HandSolder
D2: D_Small; D_SOD-323_HandSoldering
J15: Fan_3Pin; PinHeader_1x03_P2.54mm_Horizontal_NoSilk
L5: 10uH @ 400mA; L_0805_2012Metric_Pad1.15x1.40mm_HandSolder
Q7: LGE2300; TSOT-23
R12: 10k; R_0805_2012Metric_Pad1.15x1.40mm_HandSolder

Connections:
+12V: C16.1, D2.1 (K), J15.2 (+12V), R12.1; also elsewhere on the board
/3pin fan output 11/RPM_Sense_12V: J15.3 (RPM_Sense), R12.2; also elsewhere on the board
/Fan11_PWM: Q7.1 (G); also elsewhere on the board
GND: Q7.2 (S); also elsewhere on the board

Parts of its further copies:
C11, C12, C13, C14, C15: 10uF @ 25V; C_0805_2012Metric_Pad1.15x1.40mm_HandSolder
D3, D4, D5, D6, D7: D_Small; D_SOD-323_HandSoldering
J10, J11, J12, J13, J14: Fan_3Pin; PinHeader_1x03_P2.54mm_Horizontal_NoSilk
L1, L2, L3, L4, L6: 10uH @ 400mA; L_0805_2012Metric_Pad1.15x1.40mm_HandSolder
Q2, Q3, Q4, Q5, Q6: LGE2300; TSOT-23
R7, R8, R9, R10, R11: 10k; R_0805_2012Metric_Pad1.15x1.40mm_HandSolder

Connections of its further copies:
+12V: C11.1, C12.1, C13.1, C14.1, C15.1, D3.1 (K), D4.1 (K), D5.1 (K), D6.1 (K), D7.1 (K), J10.2 (+12V), J11.2 (+12V), J12.2 (+12V), J13.2 (+12V), J14.2 (+12V), R7.1, R8.1, R9.1, R10.1, R11.1; also elsewhere on the board
/3pin fan output 6/Fan_GND: C11.2, J10.1 (GND), L1.2
/3pin fan output 6/RPM_Sense_12V: J10.3 (RPM_Sense), R11.2; also elsewhere on the board
/3pin fan output 7/Fan_GND: C12.2, J11.1 (GND), L2.2
/3pin fan output 7/RPM_Sense_12V: J11.3 (RPM_Sense), R7.2; also elsewhere on the board
/3pin fan output 8/Fan_GND: C13.2, J12.1 (GND), L3.2
/3pin fan output 8/RPM_Sense_12V: J12.3 (RPM_Sense), R8.2; also elsewhere on the board
/3pin fan output 9/Fan_GND: C14.2, J13.1 (GND), L4.2
/3pin fan output 9/RPM_Sense_12V: J13.3 (RPM_Sense), R9.2; also elsewhere on the board
/3pin fan output 10/RPM_Sense_12V: J14.3 (RPM_Sense), R10.2; also elsewhere on the board
/Fan6_PWM: Q2.1 (G); also elsewhere on the board
/Fan7_PWM: Q3.1 (G); also elsewhere on the board
/Fan8_PWM: Q4.1 (G); also elsewhere on the board
/Fan9_PWM: Q5.1 (G); also elsewhere on the board
/Fan10_PWM: Q6.1 (G); also elsewhere on the board
GND: Q2.2 (S), Q3.2 (S), Q4.2 (S), Q5.2 (S), Q6.2 (S); also elsewhere on the board
unnamed: D3.2 (A), L2.1, Q3.3 (D)
unnamed: D4.2 (A), L3.1, Q4.3 (D)
unnamed: D5.2 (A), L4.1, Q5.3 (D)

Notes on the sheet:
The capacitor and inductor values don't need to be exact, bigger is (mostly) better.

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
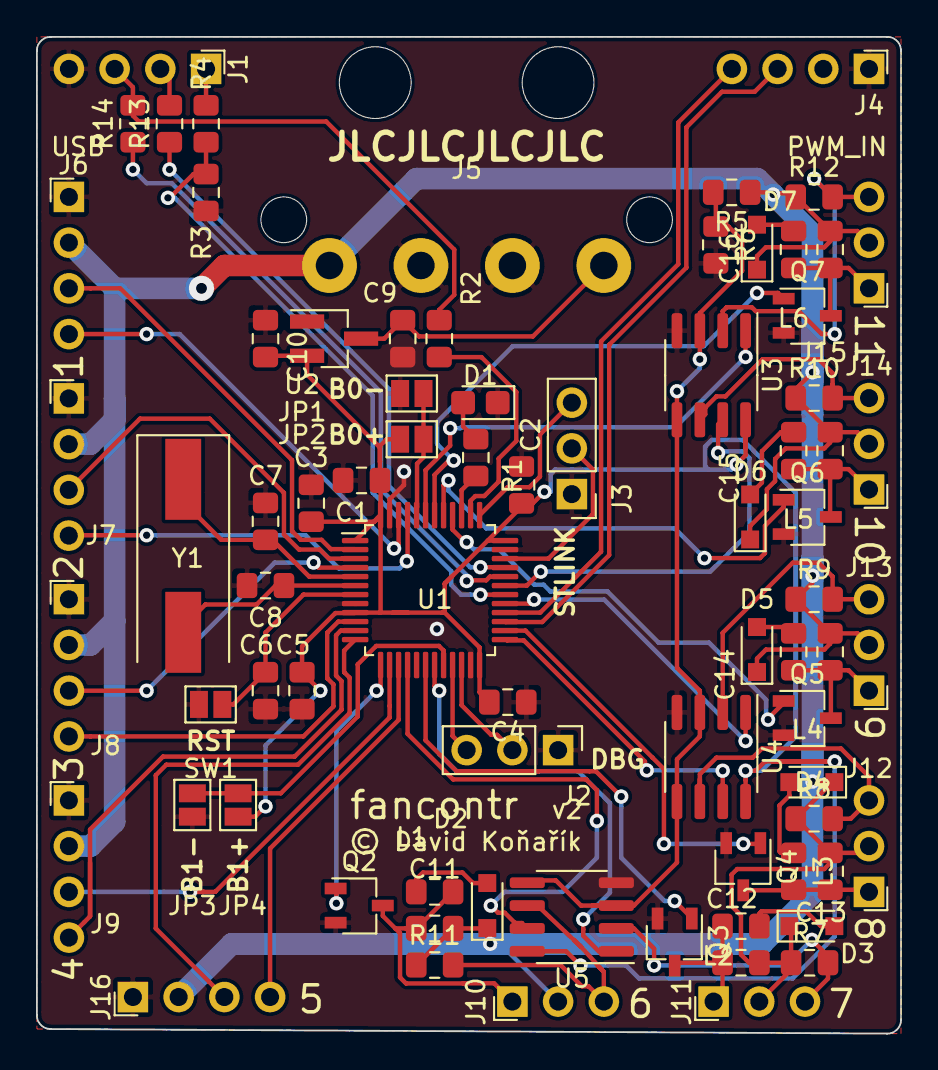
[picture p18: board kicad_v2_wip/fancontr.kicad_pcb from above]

Board: 2 copper layers, 48.0 x 55.4 mm, 76 parts (0 on the bottom side), 65 nets.

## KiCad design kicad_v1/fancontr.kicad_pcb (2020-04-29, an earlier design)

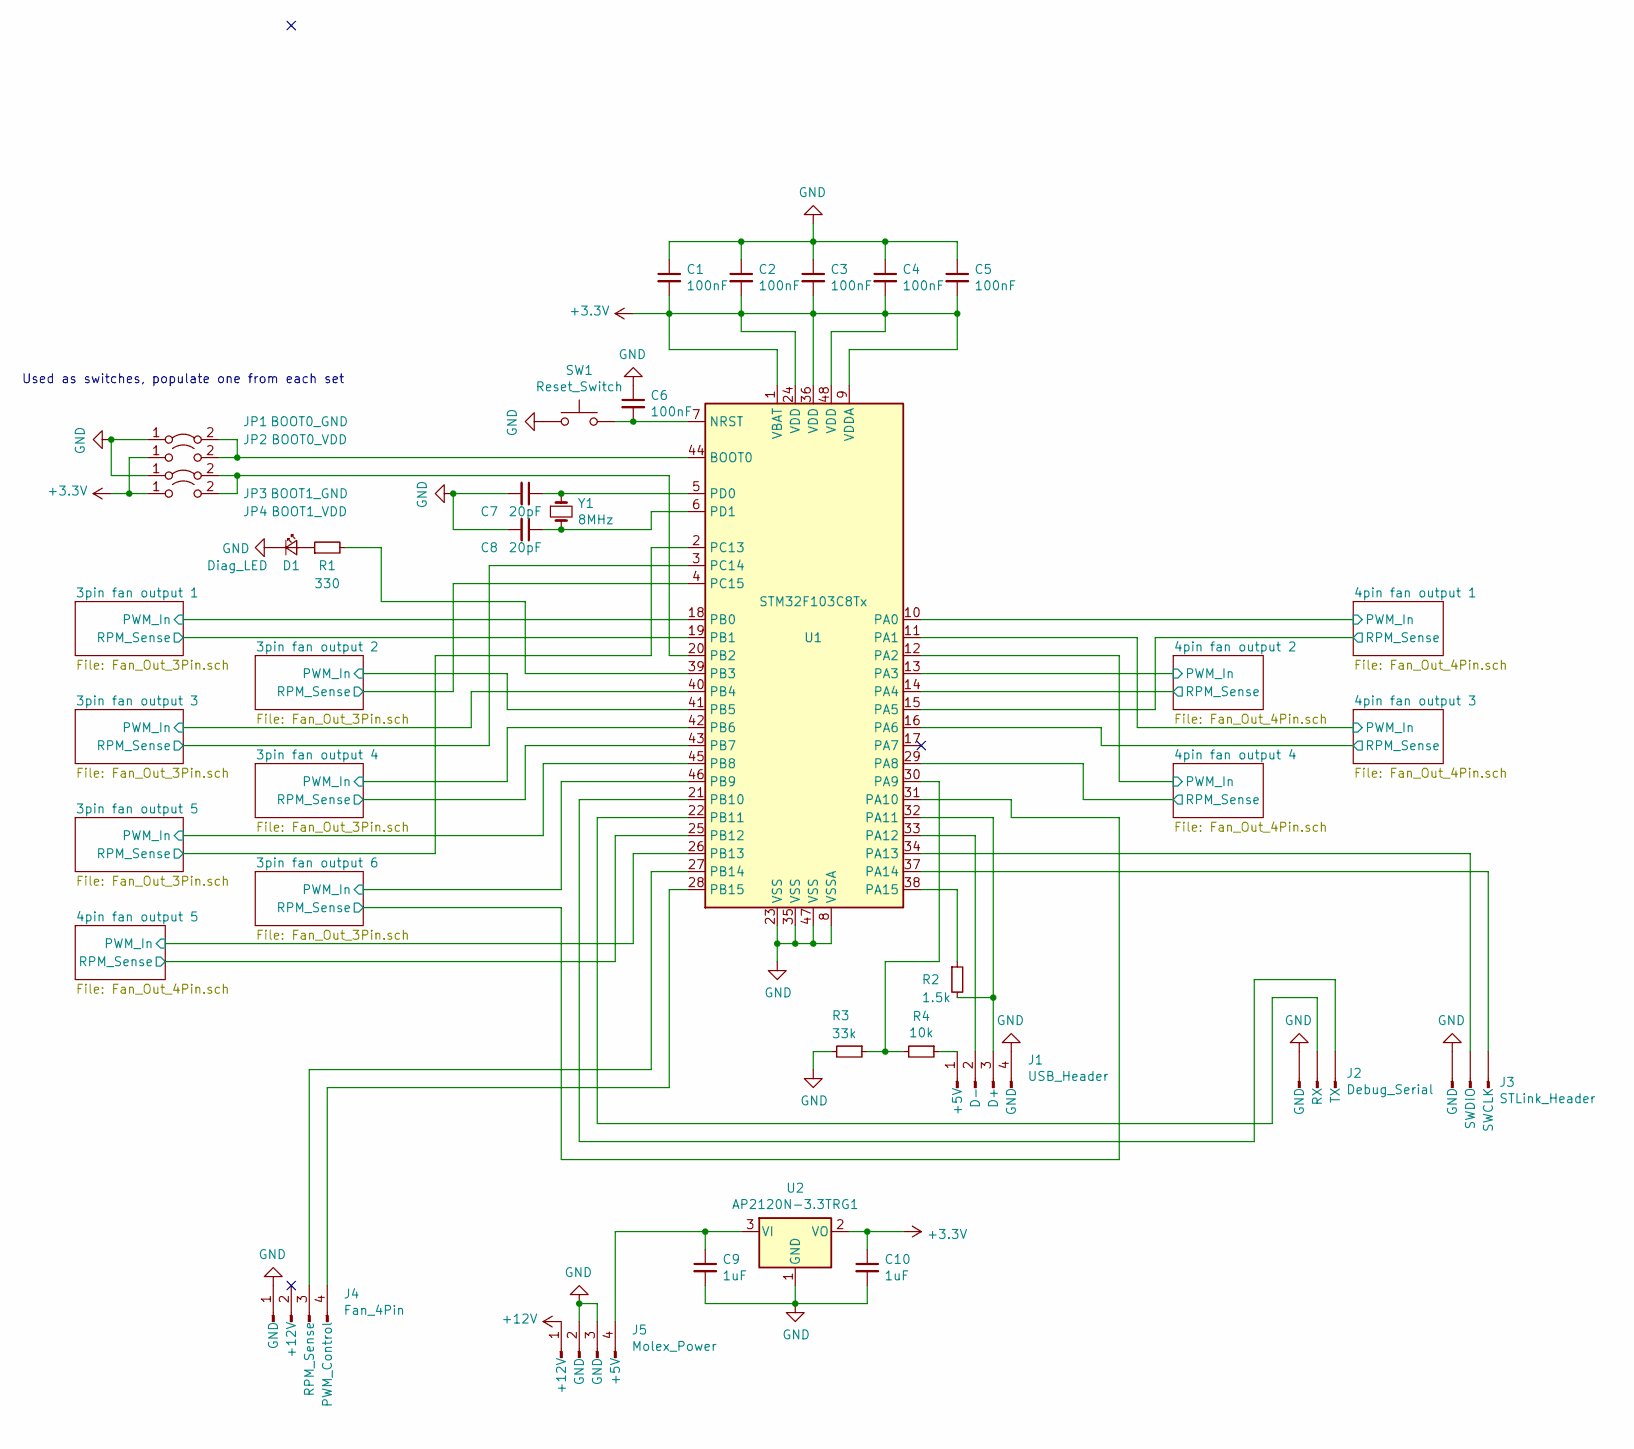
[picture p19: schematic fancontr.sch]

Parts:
C1, C2, C3, C4, C5, C6: 100nF; C_0805_2012Metric_Pad1.15x1.40mm_HandSolder
C7, C8: 20pF; C_0805_2012Metric_Pad1.15x1.40mm_HandSolder
C9, C10: 1uF; C_0805_2012Metric_Pad1.15x1.40mm_HandSolder
D1: Diag_LED; LED_0805_2012Metric_Castellated
J1: USB_Header; PinHeader_1x04_P2.54mm_Horizontal_NoSilk
J2: Debug_Serial; PinHeader_1x03_P2.54mm_Vertical
J3: STLink_Header; PinHeader_1x03_P2.54mm_Vertical
J4: Fan_4Pin; PinHeader_1x04_P2.54mm_Horizontal_NoSilk
J5: Molex_Power; MATE-N-LOK 641737-1
JP1: BOOT0_GND; SolderJumper-2_P1.3mm_Open_Pad1.0x1.5mm
JP2: BOOT0_VDD; SolderJumper-2_P1.3mm_Open_Pad1.0x1.5mm
JP3: BOOT1_GND; SolderJumper-2_P1.3mm_Open_Pad1.0x1.5mm
JP4: BOOT1_VDD; SolderJumper-2_P1.3mm_Open_Pad1.0x1.5mm
R1: 330; R_0805_2012Metric_Pad1.15x1.40mm_HandSolder
R2: 1.5k; R_0805_2012Metric_Pad1.15x1.40mm_HandSolder
R3: 33k; R_0805_2012Metric_Pad1.15x1.40mm_HandSolder
R4: 10k; R_0805_2012Metric_Pad1.15x1.40mm_HandSolder
SW1: Reset_Switch; SolderJumper-2_P1.3mm_Open_Pad1.0x1.5mm
U1: STM32F103C8Tx; LQFP-48_7x7mm_P0.5mm
U2: AP2120N-3.3TRG1; SOT-23_Handsoldering
Y1: 8MHz; Crystal_SMD_HC49-SD

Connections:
+3V3: C1.2, C2.2, C3.2, C4.2, C5.2, C10.1, JP2.1 (A), JP4.1 (A), U1.1 (VBAT), U1.9 (VDDA), U1.24 (VDD), U1.36 (VDD), U1.48 (VDD), U2.2 (VO)
+12V: J5.1 (+12V); also elsewhere on the board
/3pin fan output 1/PWM_In: U1.18 (PB0); also elsewhere on the board
/3pin fan output 1/RPM_Sense: U1.19 (PB1); also elsewhere on the board
/3pin fan output 2/PWM_In: U1.41 (PB5); also elsewhere on the board
/3pin fan output 2/RPM_Sense: U1.4 (PC15); also elsewhere on the board
/3pin fan output 3/PWM_In: U1.40 (PB4); also elsewhere on the board
/3pin fan output 3/RPM_Sense: U1.3 (PC14); also elsewhere on the board
/3pin fan output 4/PWM_In: U1.42 (PB6); also elsewhere on the board
/3pin fan output 4/RPM_Sense: U1.43 (PB7); also elsewhere on the board
/3pin fan output 5/PWM_In: U1.45 (PB8); also elsewhere on the board
/3pin fan output 5/RPM_Sense: U1.2 (PC13); also elsewhere on the board
/3pin fan output 6/PWM_In: U1.46 (PB9); also elsewhere on the board
/3pin fan output 6/RPM_Sense: U1.31 (PA10); also elsewhere on the board
/4pin fan output 1/PWM_In: U1.10 (PA0); also elsewhere on the board
/4pin fan output 1/RPM_Sense: U1.15 (PA5); also elsewhere on the board
/4pin fan output 2/PWM_In: U1.13 (PA3); also elsewhere on the board
/4pin fan output 2/RPM_Sense: U1.14 (PA4); also elsewhere on the board
/4pin fan output 3/PWM_In: U1.11 (PA1); also elsewhere on the board
/4pin fan output 3/RPM_Sense: U1.16 (PA6); also elsewhere on the board
/4pin fan output 4/PWM_In: U1.12 (PA2); also elsewhere on the board
/4pin fan output 4/RPM_Sense: U1.29 (PA8); also elsewhere on the board
/4pin fan output 5/PWM_In: U1.26 (PB13); also elsewhere on the board
/4pin fan output 5/RPM_Sense: U1.25 (PB12); also elsewhere on the board
GND: C1.1, C2.1, C3.1, C4.1, C5.1, C6.1, C7.2, C8.2, C9.2, C10.2, D1.1 (K), J1.4 (GND), J2.1 (GND), J3.1 (GND), J4.1 (GND), J5.2 (GND), J5.3 (GND), JP1.1 (A), JP3.1 (A), R3.2, SW1.1, U1.8 (VSSA), U1.23 (VSS), U1.35 (VSS), U1.47 (VSS), U2.1 (GND); also elsewhere on the board
unnamed: C6.2, SW1.2, U1.7 (NRST)
unnamed: C7.1, U1.5 (PD0), Y1.1
unnamed: C8.1, U1.6 (PD1), Y1.2
unnamed: C9.1, J5.4 (+5V), U2.3 (VI)
unnamed: D1.2 (A), R1.1
unnamed: J1.1 (+5V), R4.1
unnamed: J1.2 (D-), U1.33 (PA12)
unnamed: J1.3 (D+), R2.2, U1.32 (PA11)
unnamed: J2.2 (RX), U1.22 (PB11)
unnamed: J2.3 (TX), U1.21 (PB10)
unnamed: J3.2 (SWDIO), U1.34 (PA13)
unnamed: J3.3 (SWCLK), U1.37 (PA14)
unnamed: J4.3 (RPM_Sense), U1.27 (PB14)
unnamed: J4.4 (PWM_Control), U1.28 (PB15)
unnamed: JP1.2 (B), JP2.2 (B), U1.44 (BOOT0)
unnamed: JP3.2 (B), JP4.2 (B), U1.20 (PB2)
unnamed: R1.2, U1.39 (PB3)
unnamed: R2.1, U1.38 (PA15)
unnamed: R3.1, R4.2, U1.30 (PA9)

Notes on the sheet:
Used as switches, populate one from each set

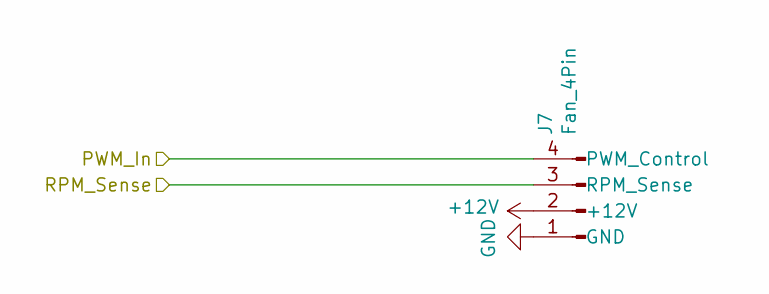
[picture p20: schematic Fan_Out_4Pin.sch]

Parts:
J6: Fan_4Pin; PinHeader_1x04_P2.54mm_Horizontal_NoSilk

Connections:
+12V: J6.2 (+12V); also elsewhere on the board
/4pin fan output 1/PWM_In: J6.4 (PWM_Control); also elsewhere on the board
/4pin fan output 1/RPM_Sense: J6.3 (RPM_Sense); also elsewhere on the board
GND: J6.1 (GND); also elsewhere on the board

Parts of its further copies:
J7, J8, J9, J16: Fan_4Pin; PinHeader_1x04_P2.54mm_Horizontal_NoSilk

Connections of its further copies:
+12V: J7.2 (+12V), J8.2 (+12V), J9.2 (+12V), J16.2 (+12V); also elsewhere on the board
/4pin fan output 2/PWM_In: J7.4 (PWM_Control); also elsewhere on the board
/4pin fan output 2/RPM_Sense: J7.3 (RPM_Sense); also elsewhere on the board
/4pin fan output 3/PWM_In: J8.4 (PWM_Control); also elsewhere on the board
/4pin fan output 3/RPM_Sense: J8.3 (RPM_Sense); also elsewhere on the board
/4pin fan output 4/PWM_In: J9.4 (PWM_Control); also elsewhere on the board
/4pin fan output 4/RPM_Sense: J9.3 (RPM_Sense); also elsewhere on the board
/4pin fan output 5/PWM_In: J16.4 (PWM_Control); also elsewhere on the board
/4pin fan output 5/RPM_Sense: J16.3 (RPM_Sense); also elsewhere on the board
GND: J7.1 (GND), J8.1 (GND), J9.1 (GND), J16.1 (GND); also elsewhere on the board

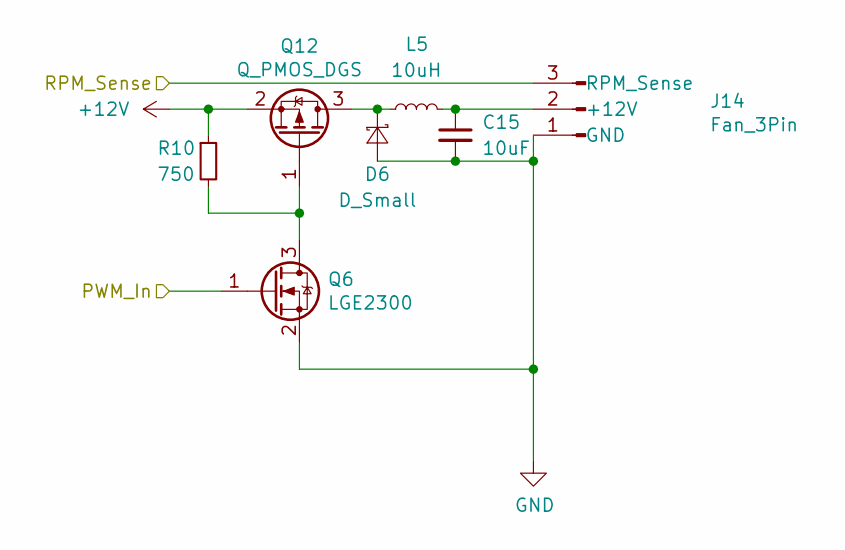
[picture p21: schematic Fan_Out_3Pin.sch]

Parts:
C16: 10uF; C_0805_2012Metric_Pad1.15x1.40mm_HandSolder
D2: D_Small; D_SOD-323_HandSoldering
J15: Fan_3Pin; PinHeader_1x03_P2.54mm_Horizontal_NoSilk
L5: 10uH; L_0805_2012Metric_Pad1.15x1.40mm_HandSolder
Q7: LGE2300; TSOT-23
Q13: Q_PMOS_DGS; TSOT-23
R11: 750; R_0805_2012Metric_Pad1.15x1.40mm_HandSolder

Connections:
+12V: Q13.2 (S), R11.1; also elsewhere on the board
/3pin fan output 1/PWM_In: Q7.1 (G); also elsewhere on the board
/3pin fan output 1/RPM_Sense: J15.3 (RPM_Sense); also elsewhere on the board
GND: C16.2, D2.2 (A), J15.1 (GND), Q7.2 (S); also elsewhere on the board
unnamed: Q7.3 (D), Q13.1 (G), R11.2

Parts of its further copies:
C11, C12, C13, C14, C15: 10uF; C_0805_2012Metric_Pad1.15x1.40mm_HandSolder
D3, D4, D5, D6, D7: D_Small; D_SOD-323_HandSoldering
J10, J11, J12, J13, J14: Fan_3Pin; PinHeader_1x03_P2.54mm_Horizontal_NoSilk
L1, L2, L3, L4, L6: 10uH; L_0805_2012Metric_Pad1.15x1.40mm_HandSolder
Q2, Q3, Q4, Q5, Q6: LGE2300; TSOT-23
Q8, Q9, Q10, Q11, Q12: Q_PMOS_DGS; TSOT-23
R6, R7, R8, R9, R10: 750; R_0805_2012Metric_Pad1.15x1.40mm_HandSolder

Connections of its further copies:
+12V: Q8.2 (S), Q9.2 (S), Q10.2 (S), Q11.2 (S), Q12.2 (S), R6.1, R7.1, R8.1, R9.1, R10.1; also elsewhere on the board
/3pin fan output 2/PWM_In: Q6.1 (G); also elsewhere on the board
/3pin fan output 2/RPM_Sense: J14.3 (RPM_Sense); also elsewhere on the board
/3pin fan output 3/PWM_In: Q3.1 (G); also elsewhere on the board
/3pin fan output 3/RPM_Sense: J11.3 (RPM_Sense); also elsewhere on the board
/3pin fan output 4/PWM_In: Q4.1 (G); also elsewhere on the board
/3pin fan output 4/RPM_Sense: J12.3 (RPM_Sense); also elsewhere on the board
/3pin fan output 5/PWM_In: Q5.1 (G); also elsewhere on the board
/3pin fan output 5/RPM_Sense: J13.3 (RPM_Sense); also elsewhere on the board
/3pin fan output 6/PWM_In: Q2.1 (G); also elsewhere on the board
/3pin fan output 6/RPM_Sense: J10.3 (RPM_Sense); also elsewhere on the board
GND: C11.2, C12.2, C13.2, C14.2, C15.2, D3.2 (A), D4.2 (A), D5.2 (A), D6.2 (A), D7.2 (A), J10.1 (GND), J11.1 (GND), J12.1 (GND), J13.1 (GND), J14.1 (GND), Q2.2 (S), Q3.2 (S), Q4.2 (S), Q5.2 (S), Q6.2 (S); also elsewhere on the board
unnamed: C11.1, J10.2 (+12V), L1.2
unnamed: C12.1, J11.2 (+12V), L2.2
unnamed: C13.1, J12.2 (+12V), L3.2
unnamed: C14.1, J13.2 (+12V), L4.2
unnamed: D3.1 (K), L2.1, Q9.3 (D)
unnamed: D4.1 (K), L3.1, Q10.3 (D)
unnamed: D5.1 (K), L4.1, Q11.3 (D)
unnamed: Q2.3 (D), Q8.1 (G), R6.2
unnamed: Q3.3 (D), Q9.1 (G), R7.2
unnamed: Q4.3 (D), Q10.1 (G), R8.2
unnamed: Q5.3 (D), Q11.1 (G), R9.2
unnamed: Q6.3 (D), Q12.1 (G), R10.2

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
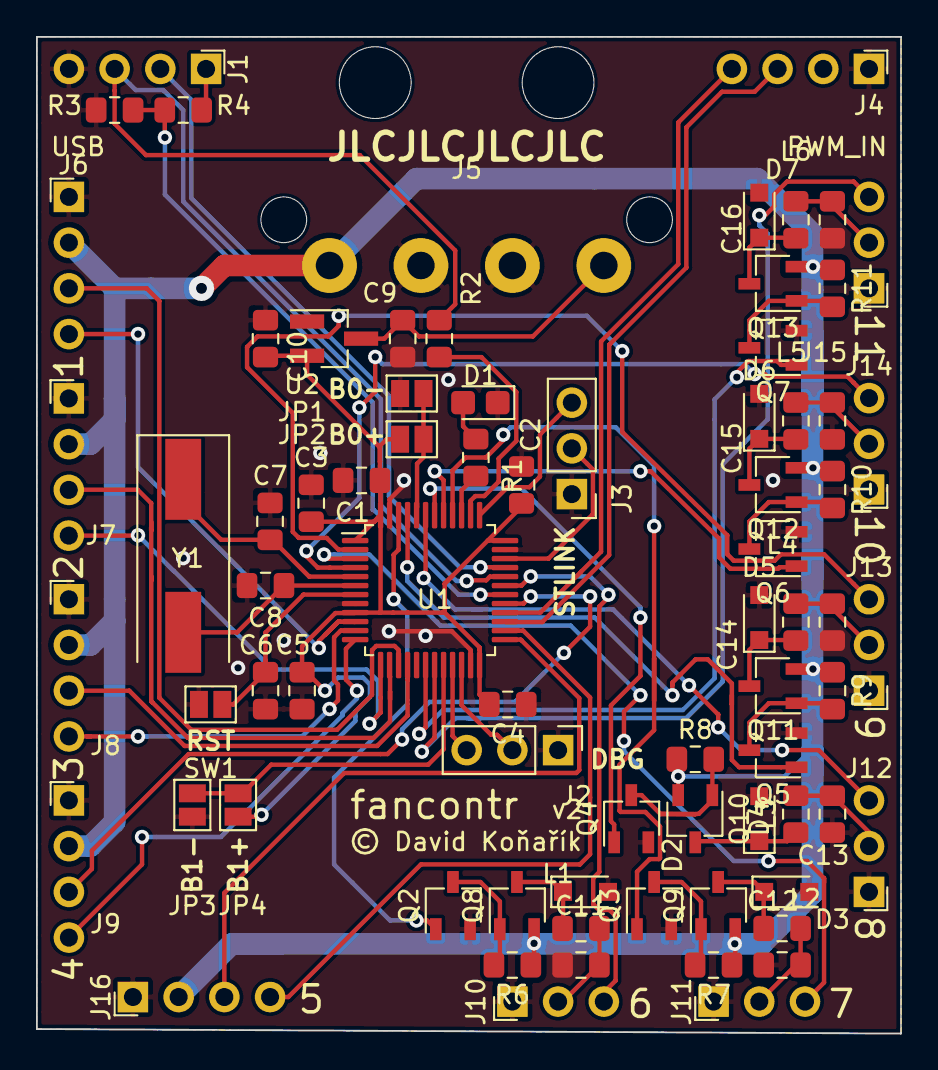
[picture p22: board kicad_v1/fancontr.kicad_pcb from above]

Board: 2 copper layers, 48.0 x 55.4 mm, 75 parts (0 on the bottom side), 62 nets.

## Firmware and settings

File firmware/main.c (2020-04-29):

/*
    ChibiOS - Copyright (C) 2006..2018 Giovanni Di Sirio

    Licensed under the Apache License, Version 2.0 (the "License");
    you may not use this file except in compliance with the License.
    You may obtain a copy of the License at

        http://www.apache.org/licenses/LICENSE-2.0

    Unless required by applicable law or agreed to in writing, software
    distributed under the License is distributed on an "AS IS" BASIS,
    WITHOUT WARRANTIES OR CONDITIONS OF ANY KIND, either express or implied.
    See the License for the specific language governing permissions and
    limitations under the License.
*/

#include "ch.h"
#include "hal.h"

#include "fc_shell.h"
#include "fc_fan.h"
#include "fc_fan_in.h"
#include "fc_tempsrc.h"

/*
 * Blinker thread, times are in milliseconds.
 */
static THD_WORKING_AREA(waThread1, 128);
static __attribute__((noreturn)) THD_FUNCTION(Thread1, arg) {

    (void)arg;
    chRegSetThreadName("blinker");
    while (true) {
        systime_t time = 500;
        palClearPad(GPIOB, GPIOB_LED);
        chThdSleepMilliseconds(time);
        palSetPad(GPIOB, GPIOB_LED);
        chThdSleepMilliseconds(time);
    }
}

/*
 * Application entry point.
 */
int main(void) {

    /*
     * System initializations.
     * - HAL initialization, this also initializes the configured device drivers
     *   and performs the board-specific initializations.
     * - Kernel initialization, the main() function becomes a thread and the
     *   RTOS is active.
     */
    halInit();
    chSysInit();

    /*
     * Creates the blinker thread.
     */
    chThdCreateStatic(waThread1, sizeof(waThread1), NORMALPRIO, Thread1, NULL);

    fan_init_ports();
    // TODO: Save/load profiles
    fan_init_control_blank();
    fan_in_init();
    tempsrc_virt_init();
    setup_shell();
}

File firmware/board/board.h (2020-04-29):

/*
    ChibiOS - Copyright (C) 2006..2018 Giovanni Di Sirio

    Licensed under the Apache License, Version 2.0 (the "License");
    you may not use this file except in compliance with the License.
    You may obtain a copy of the License at

        http://www.apache.org/licenses/LICENSE-2.0

    Unless required by applicable law or agreed to in writing, software
    distributed under the License is distributed on an "AS IS" BASIS,
    WITHOUT WARRANTIES OR CONDITIONS OF ANY KIND, either express or implied.
    See the License for the specific language governing permissions and
    limitations under the License.
*/

#ifndef _BOARD_H_
#define _BOARD_H_

/*
 * Setup for the LeafLabs Maple Mini.
 */

/*
 * Board identifier.
 */
#define BOARD_FANCONTR
#define BOARD_NAME              "Fancontr"

/*
 * Board frequencies.
 */
#define STM32_HSECLK            8000000

/*
 * MCU type, supported types are defined in ./os/hal/platforms/hal_lld.h.
 */
#define STM32F103xB

/*
 * IO pins assignments
 *
 * numbering is sorted by onboard/connectors, as from the schematics in
 * https://github.com/leaflabs/maplemini
 */

/* on-board */

#define GPIOA_USBDP_PULLUP      15
#define GPIOB_LED               3
#define GPIOD_OSC_IN            0
#define GPIOD_OSC_OUT           1

#define GPIOC_TAMPER_RTC        13
#define GPIOC_OSC32_IN          14
#define GPIOC_OSD32_OUT         15
#define GPIOA_USART2_CTS        0
#define GPIOA_USART2_RTS        1
#define GPIOA_USART2_TX         2
#define GPIOA_USART2_RX         3
#define GPIOA_SPI1_NSS          4
#define GPIOA_SPI1_SCK          5
#define GPIOA_SPI1_MISO         6
#define GPIOA_SPI1_MOSI         7
#define GPIOB_ADC12_IN8         0
#define GPIOB_BOOT1             2
#define GPIOB_I2C2_SCL          10
#define GPIOB_I2C2_SDA          11

#define GPIOB_SPI2_NSS          12
#define GPIOB_SPI2_SCK          13
#define GPIOB_SPI2_MISO         14
#define GPIOB_SPI2_MOSI         15
#define GPIOA_USART1_CK         8
#define GPIOA_USART1_TX         9
#define GPIOA_USART1_RX         10
#define GPIOA_USBDM             11
#define GPIOA_USBDP             12
#define GPIOA_JTMS              13
#define GPIOA_JTCK              14
#define GPIOA_JTDI              15
#define GPIOB_JTDO              3
#define GPIOB_JTRST             4
#define GPIOB_I2C1_SMBA         5
#define GPIOB_I2C1_SCL          6
#define GPIOB_I2C1_SDA          7
#define GPIOB_BOOT0_BUTTON      8

/*
 * I/O ports initial setup, this configuration is established soon after reset
 * in the initialization code.
 *
 * The digits have the following meaning:
 *   0 - Analog input.
 *   1 - Push Pull output 10MHz.
 *   2 - Push Pull output 2MHz.
 *   3 - Push Pull output 50MHz.
 *   4 - Digital input.
 *   5 - Open Drain output 10MHz.
 *   6 - Open Drain output 2MHz.
 *   7 - Open Drain output 50MHz.
 *   8 - Digital input with PullUp or PullDown resistor depending on ODR.
 *   9 - Alternate Push Pull output 10MHz.
 *   A - Alternate Push Pull output 2MHz.
 *   B - Alternate Push Pull output 50MHz.
 *   C - Reserved.
 *   D - Alternate Open Drain output 10MHz.
 *   E - Alternate Open Drain output 2MHz.
 *   F - Alternate Open Drain output 50MHz.
 * Please refer to the STM32 Reference Manual for details.
 */

/*
 * Port A setup.
 * PA15 - Push Pull output  (USB switch).
 */
#define VAL_GPIOACRL            0x8888BBBB      /*  PA7...PA0 */
#define VAL_GPIOACRH            0x38888888      /* PA15...PA8 */
#define VAL_GPIOAODR            0xFFFFFFFF

/*
 * Port B setup.
 * PB3  - Push Pull output  (LED).
 * PB10 - Alternate output  (USART3 TX).
 * PB11 - Normal input      (USART3 RX).
 * Fan PWM pins (TODO: Document)
 */
#define VAL_GPIOBCRL            0x8BBB388B      /*  PB7...PB0 */
#define VAL_GPIOBCRH            0x47B84BBB      /* PB15...PB8 */
#define VAL_GPIOBODR            0xFFFFFFFF

/*
 * Port C setup.
 * Everything input with pull-up
 */
#define VAL_GPIOCCRL            0x88888888      /*  PC7...PC0 */
#define VAL_GPIOCCRH            0x88888888      /* PC15...PC8 */
#define VAL_GPIOCODR            0xFFFFFFFF

/*
 * Port D setup.
 * Everything input with pull-up except:
 * PD0  - Normal input (XTAL).
 * PD1  - Normal input (XTAL).
 */
#define VAL_GPIODCRL            0x88888844      /*  PD7...PD0 */
#define VAL_GPIODCRH            0x88888888      /* PD15...PD8 */
#define VAL_GPIODODR            0xFFFFFFFF

/*
 * Port E setup.
 * Everything input with pull-up
 */
#define VAL_GPIOECRL            0x88888888      /*  PE7...PE0 */
#define VAL_GPIOECRH            0x88888888      /* PE15...PE8 */
#define VAL_GPIOEODR            0xFFFFFFFF

/*
 * USB bus activation macro, required by the USB driver.
 */
#define usb_lld_connect_bus(usbp) palSetPad(GPIOA, GPIOA_USBDP_PULLUP)

/*
 * USB bus de-activation macro, required by the USB driver.
 */
#define usb_lld_disconnect_bus(usbp) palClearPad(GPIOA, GPIOA_USBDP_PULLUP)

#if !defined(_FROM_ASM_)
#ifdef __cplusplus
extern "C" {
#endif
  void boardInit(void);
#ifdef __cplusplus
}
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

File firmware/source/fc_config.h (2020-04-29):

#pragma once

#include "hal.h"

enum ShellPort {
    ShellPort_USB,
    ShellPort_UART,
};

#define SHELL_PORT ShellPort_UART

#define EOL "\r\n"

struct FanPort {
    const char *name;
    _Bool is_4_pin;
    ioline_t pwm_line;
    ioline_t tacho_line;
    PWMDriver *pwm_driver;
    uint8_t pwm_channel;
};

#define FAN_PORT_COUNT 11
extern struct FanPort FAN_PORTS[];

#define FAN_4PIN_PWM_CLOCK 72000000
#define FAN_4PIN_PWM_PERIOD 500
#define FAN_3PIN_PWM_CLOCK 72000000
#define FAN_3PIN_PWM_PERIOD 500

// In milliseconds
#define TACHO_TIMER_PERIOD 500
#define CONTROL_TIMER_PERIOD 100

struct FanInPort {
    const char *name;
    ioline_t pwm_line;
    ioline_t tacho_line;
};

#define FAN_IN_PORT_COUNT 0
extern struct FanInPort FAN_IN_PORTS[];

#define FAN_IN_PWM_AVG_POINTS 8

#define TEMPSRC_VIRT_COUNT 4

#define FAN_GMAP_PTS 10

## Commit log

2020-04-29 Hardware v1
    [Fan_Out_3Pin.sch, Fan_Out_4Pin.sch, cost_calc.ods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]
2020-04-29 Hardware v2 WIP
    [Fan_Out_3Pin.sch, Fan_Out_4Pin.sch, cost_calc.ods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]

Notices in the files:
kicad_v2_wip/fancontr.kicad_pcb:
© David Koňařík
